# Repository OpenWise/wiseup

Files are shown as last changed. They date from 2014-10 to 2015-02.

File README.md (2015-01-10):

WiseUp
======

Wiseup is an intelligent home assistant open source framework that consists of three basic devices Gateway, Mediators and Sensors.

##Gateway
  Based on Raspberry Pi (Galileo/Edison in the future). All data is saved in this gateway that backs up the data on Cloud      service.
  All the important analytic scripts are running locally on the Gateway and analyzing sensor data every 3 seconds.
  
  Important modules
  - Wiseup service - this layer communicates with the sensors using Wiseup protocol.
  - Node.js services - this layer contains Web Service, connection to Mongo DB (local DB) and connection to Redis Service.
  - Redis service - Publish and Subscribe feature, also for fast data storage.
  - Mongo DB - local database.
  - Analytic services - based on node.js, executes analysis script on DB for detecting sensors features.
  - And more ...

##Mediator
  Main work frequency is 2.4Ghz with private protocol, but what if we want to use other sensors from EBay or other brands?
  For that we have the mediators that will convert from our protocol and frequency to other so we'll be able to consume
  other sensors.
  
##Sensors
  We have our own sensors running on batteries or directly from 5V power.
  
##Communication 
  nRF24l01 - 2.4Ghz very low cost and low power transceiver.
  
  RFComm - Private protocol for sensors/gateway communication. 

##Developers
- Yevgeniy Kiveisha - Linux and Embedded.
- Sharon Elihis - PCB Designer and JavaScript developer.
- Aviv Ron - Architect and senior software developer.
- Yuri Shapiro - SolidWorks designer and architect.
- Jennifer Kiveisha - UI Designer and web client developer.
- Roy Beiser - Architect

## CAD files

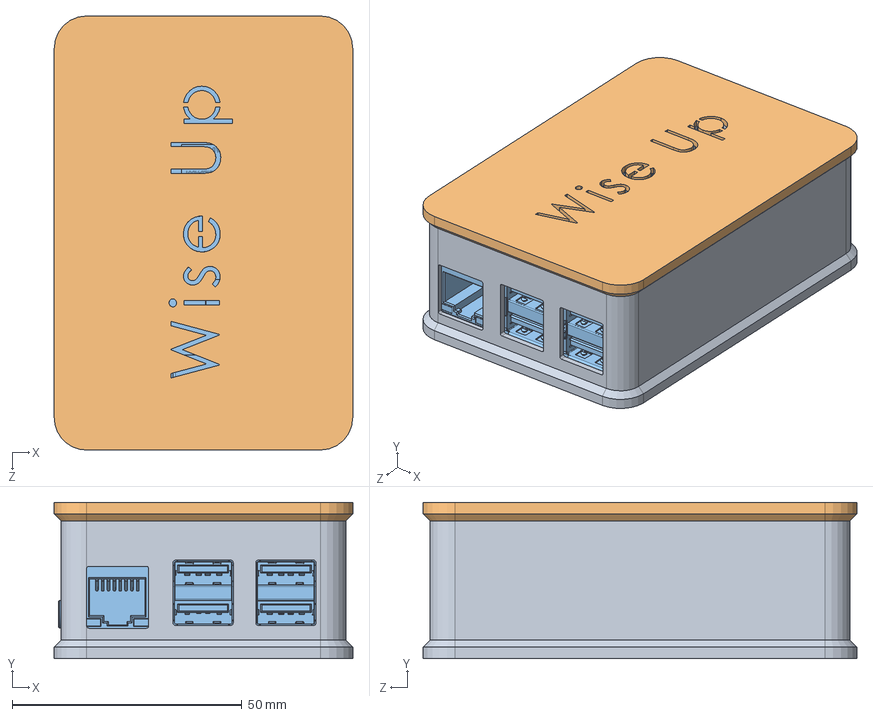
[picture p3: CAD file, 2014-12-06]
design/enclosure-design/Gateway Enclosure/Raspberrypi_B+/WiseUp - Assembly ver 2.SLDASM
65.0 x 34.0 x 94.5 mm
Case Rasp Bplus - Bottom
Case Rasp Bplus - Top
raspberrypi_b_+

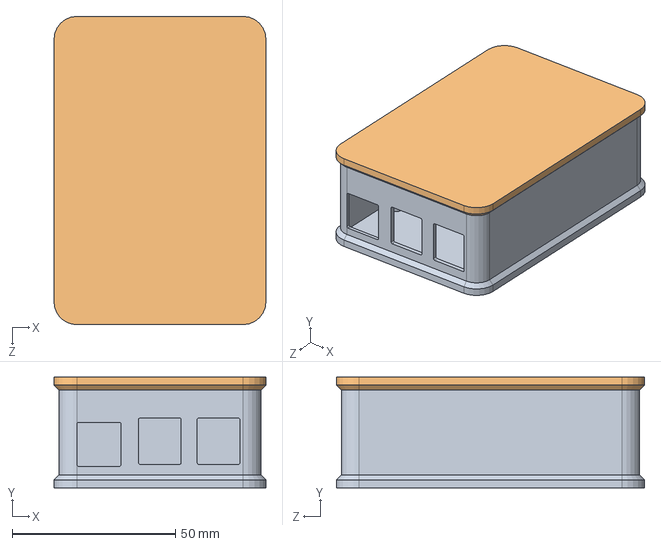
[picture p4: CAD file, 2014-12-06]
design/enclosure-design/Gateway Enclosure/Raspberrypi_B+/WiseUp - Case RBpi Bplus.SLDASM
65.0 x 34.0 x 94.5 mm
Case Rasp Bplus - Bottom
Case Rasp Bplus - Top

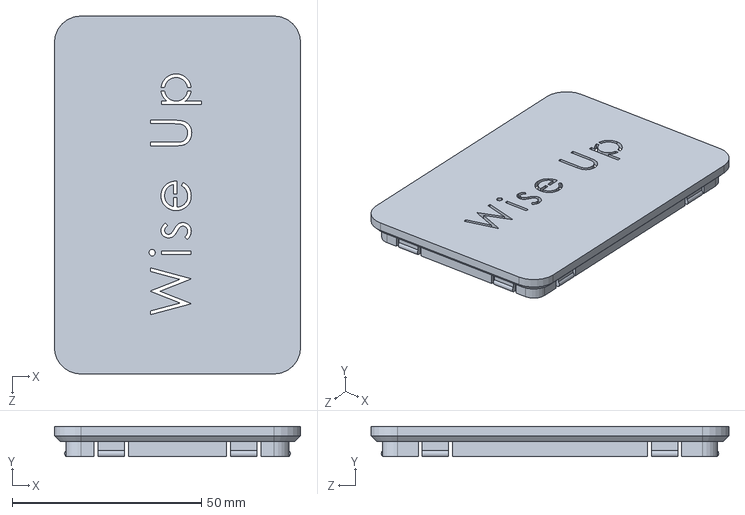
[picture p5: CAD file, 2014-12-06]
design/enclosure-design/Gateway Enclosure/Raspberrypi_B+/Case Rasp Bplus - Top.SLDPRT
65.0 x 8.00 x 94.5 mm

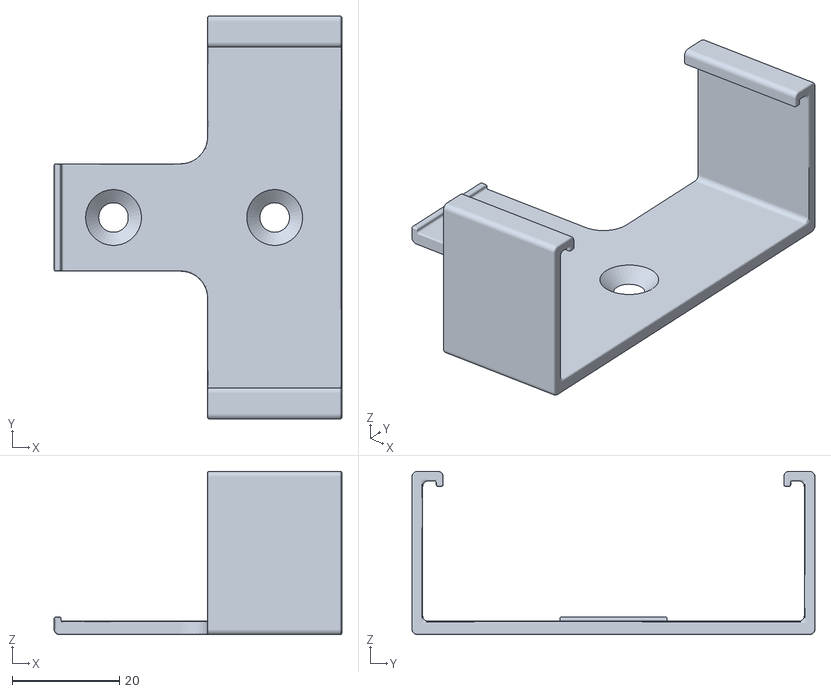
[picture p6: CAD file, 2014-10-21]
design/enclosure-design/microcontroller-gateway/Support 1.1.STL
53.6 x 75.0 x 30.4

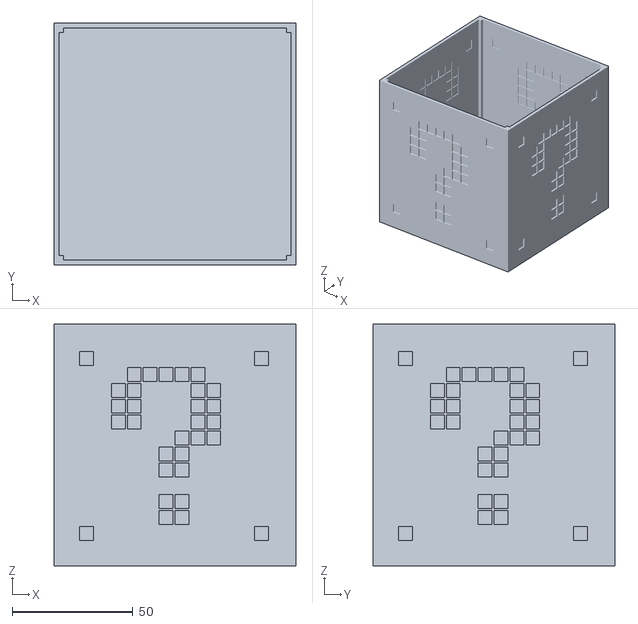
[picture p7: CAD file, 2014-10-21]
design/enclosure-design/qbox.stl
100.0 x 100.0 x 100.0

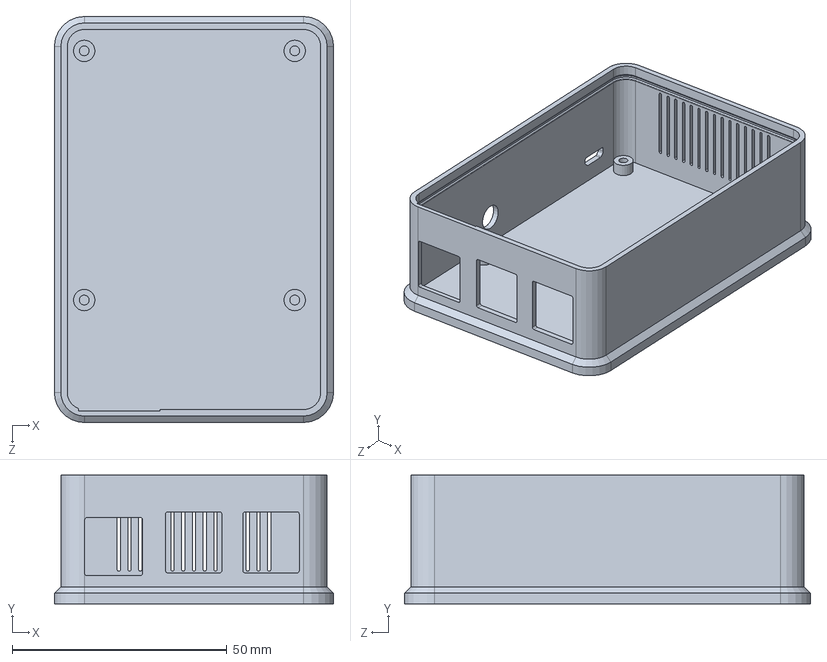
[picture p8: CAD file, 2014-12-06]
design/enclosure-design/Gateway Enclosure/Raspberrypi_B+/Case Rasp Bplus - Bottom.SLDPRT
65.0 x 30.0 x 94.5 mm

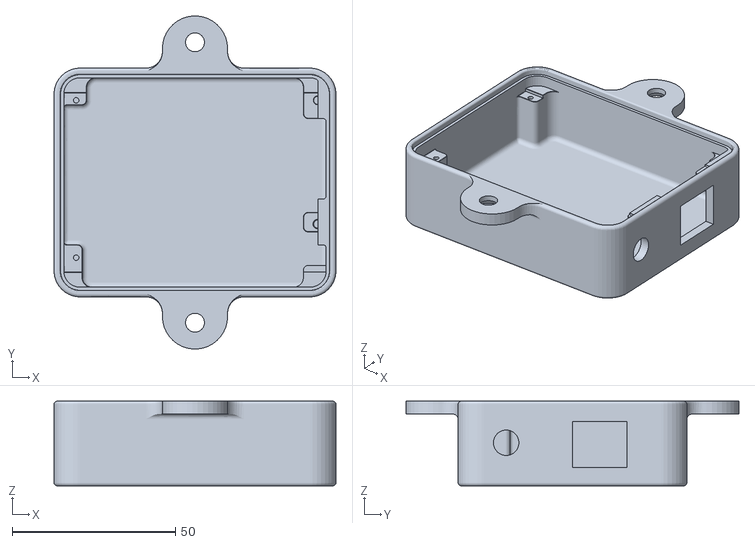
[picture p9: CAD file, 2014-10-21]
design/enclosure-design/microcontroller-gateway/BOX_UP Support 1.1.STL
86.5 x 102.1 x 26.0

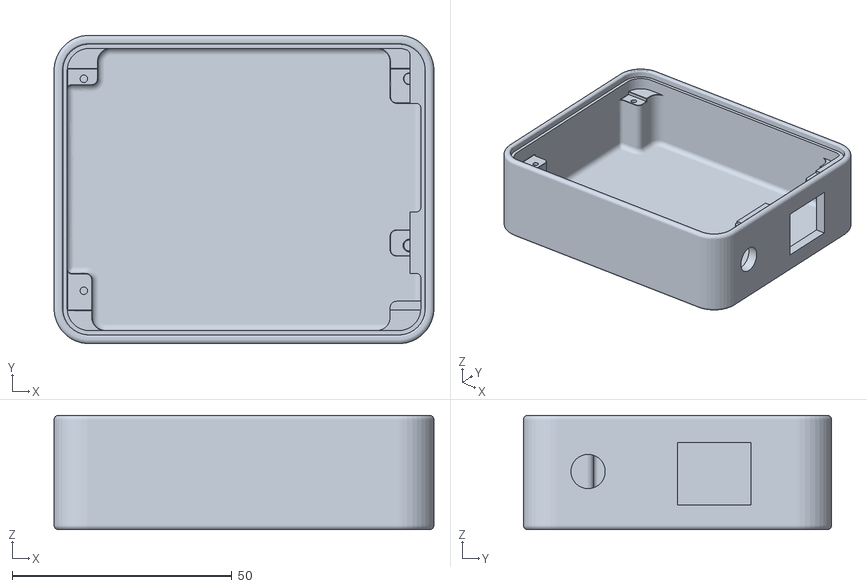
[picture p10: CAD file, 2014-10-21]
design/enclosure-design/microcontroller-gateway/BOX_UP 1.1.STL
86.5 x 70.2 x 26.0

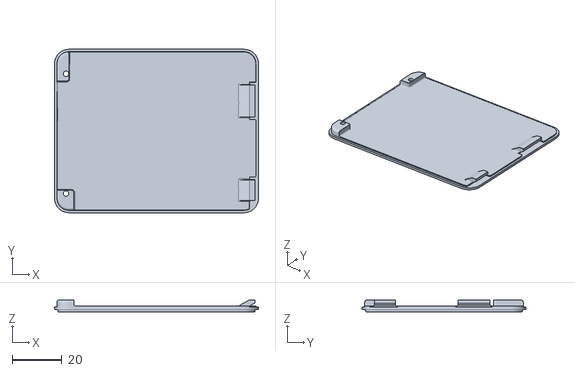
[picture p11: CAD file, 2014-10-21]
design/enclosure-design/microcontroller-gateway/Cover 3.1.STL
82.2 x 65.9 x 5.00

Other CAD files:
design/enclosure-design/Gateway Enclosure/Raspberrypi_B+/Case Rasp Bplus - Bottom.STL
design/enclosure-design/Gateway Enclosure/Raspberrypi_B+/Case Rasp Bplus - Top.STL

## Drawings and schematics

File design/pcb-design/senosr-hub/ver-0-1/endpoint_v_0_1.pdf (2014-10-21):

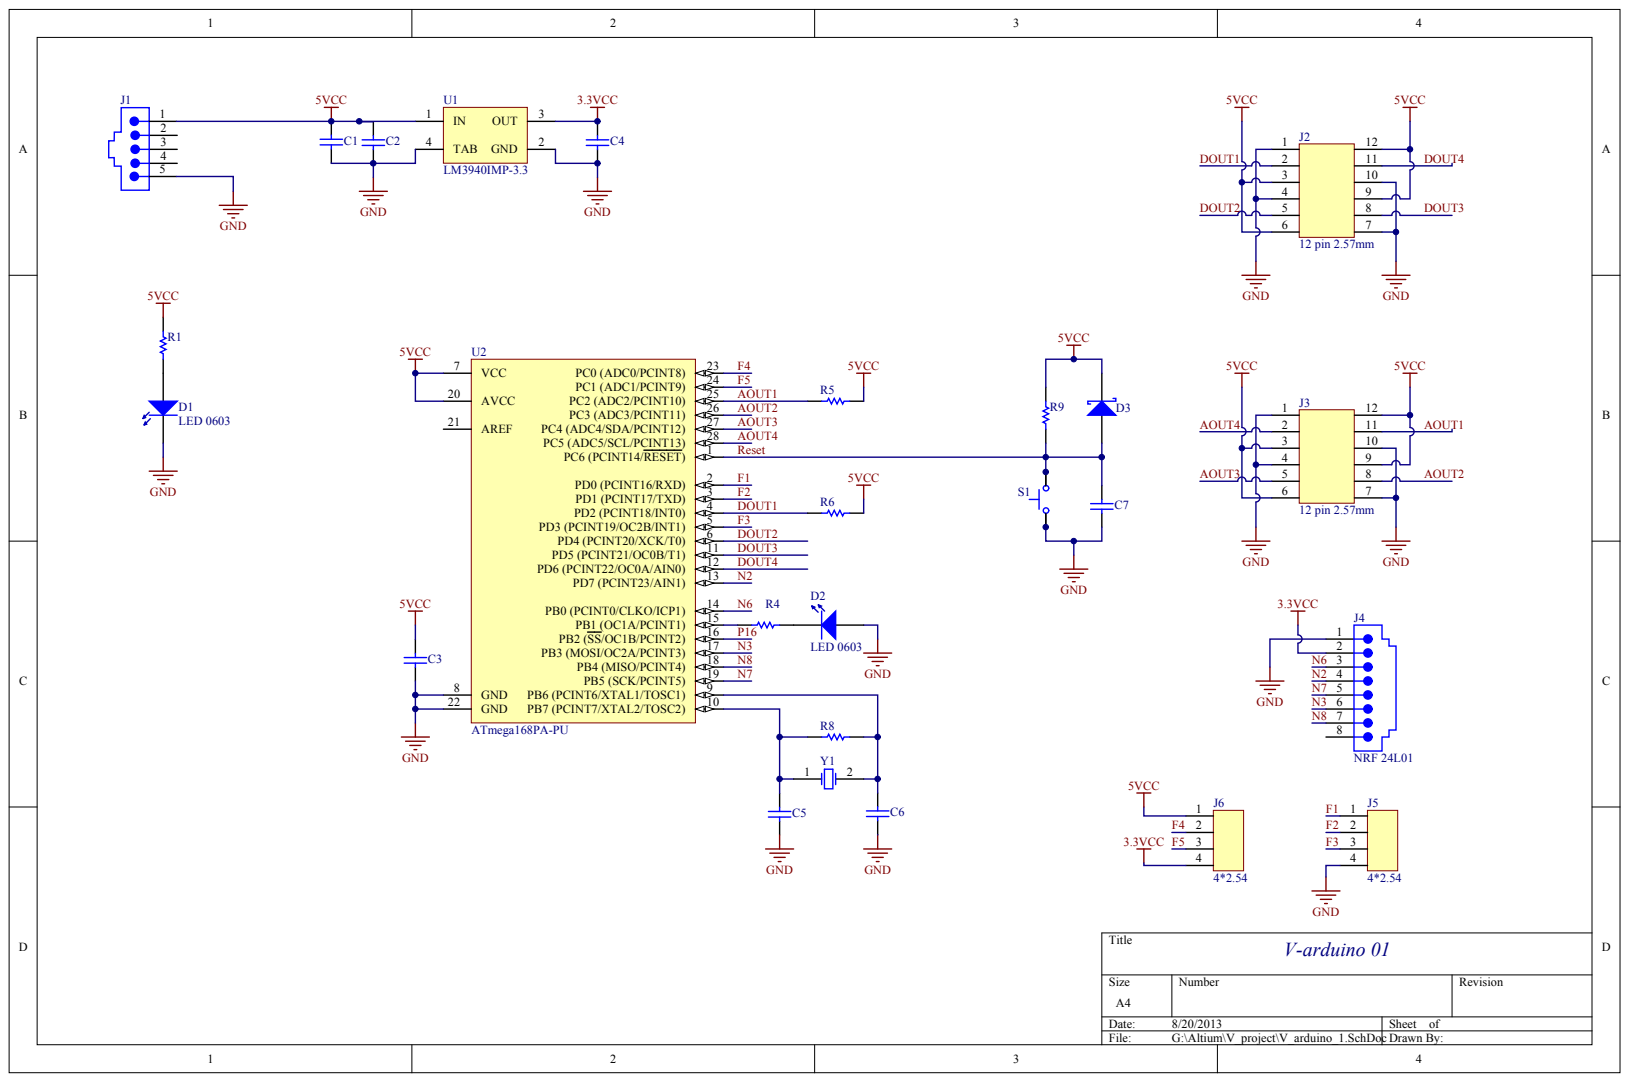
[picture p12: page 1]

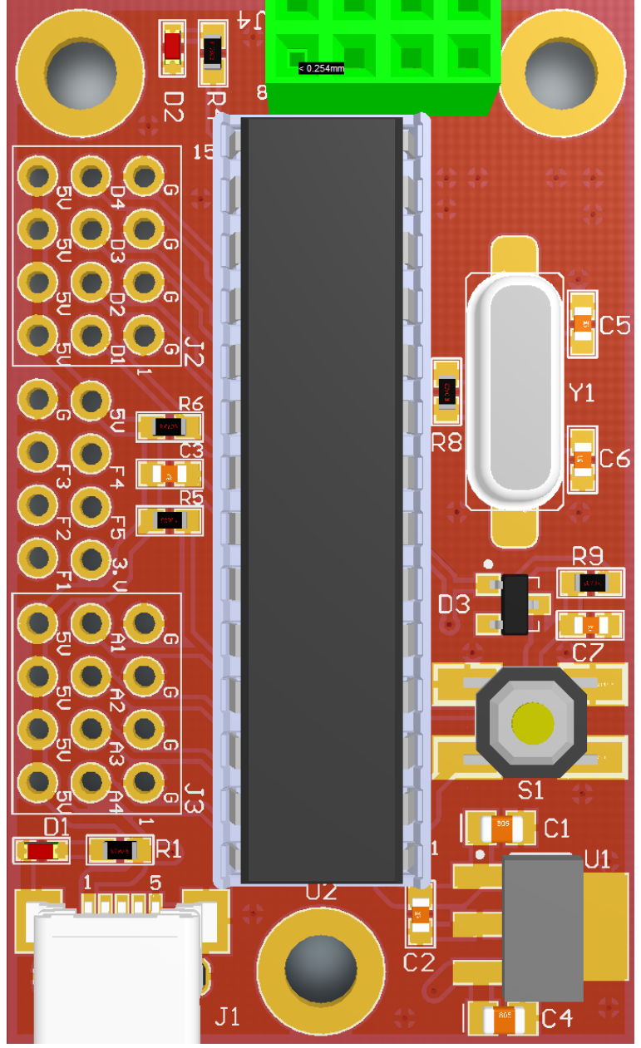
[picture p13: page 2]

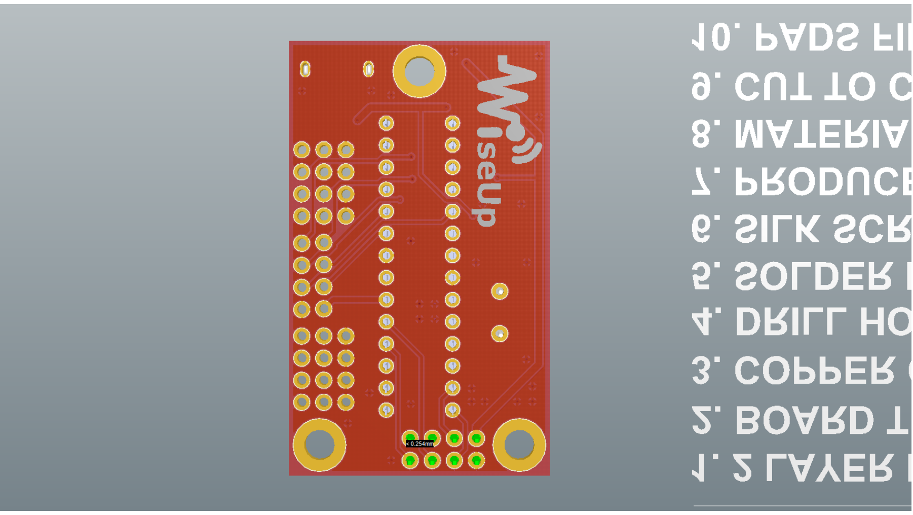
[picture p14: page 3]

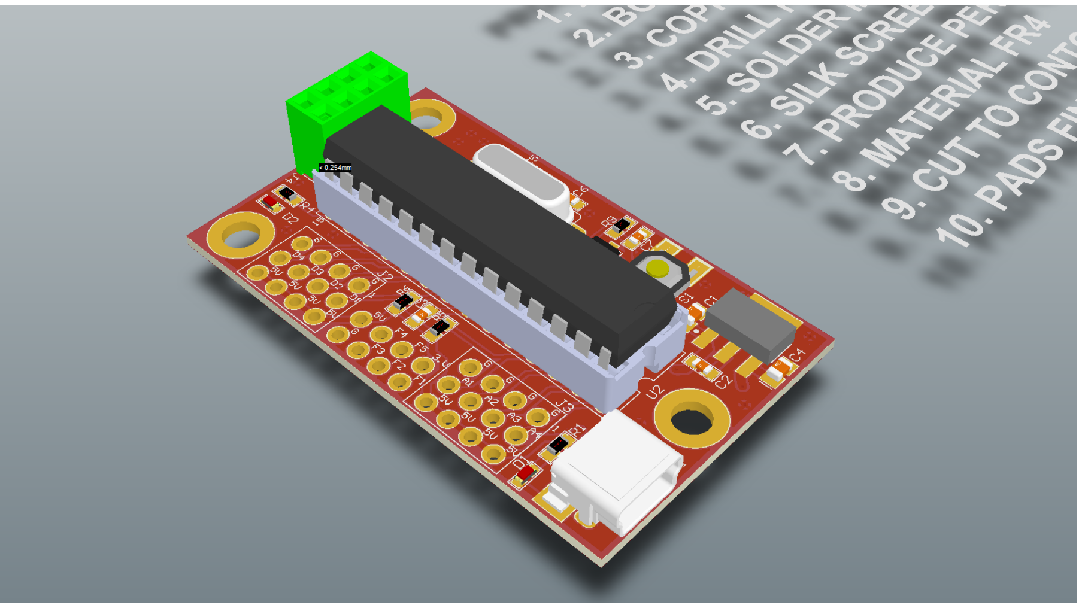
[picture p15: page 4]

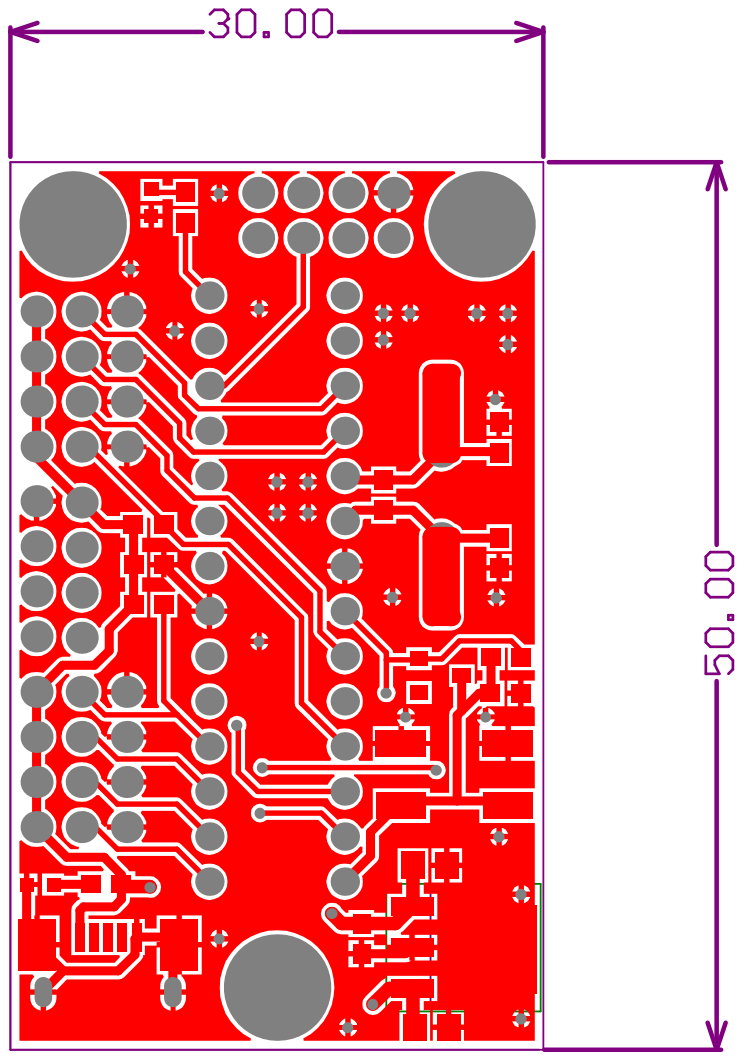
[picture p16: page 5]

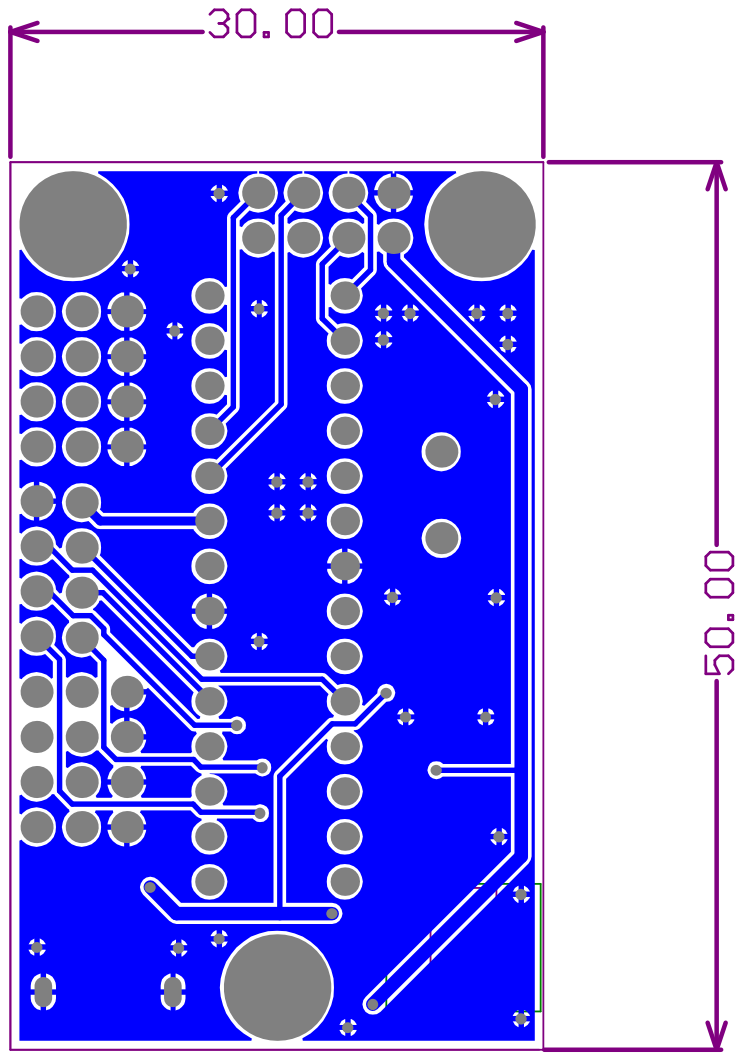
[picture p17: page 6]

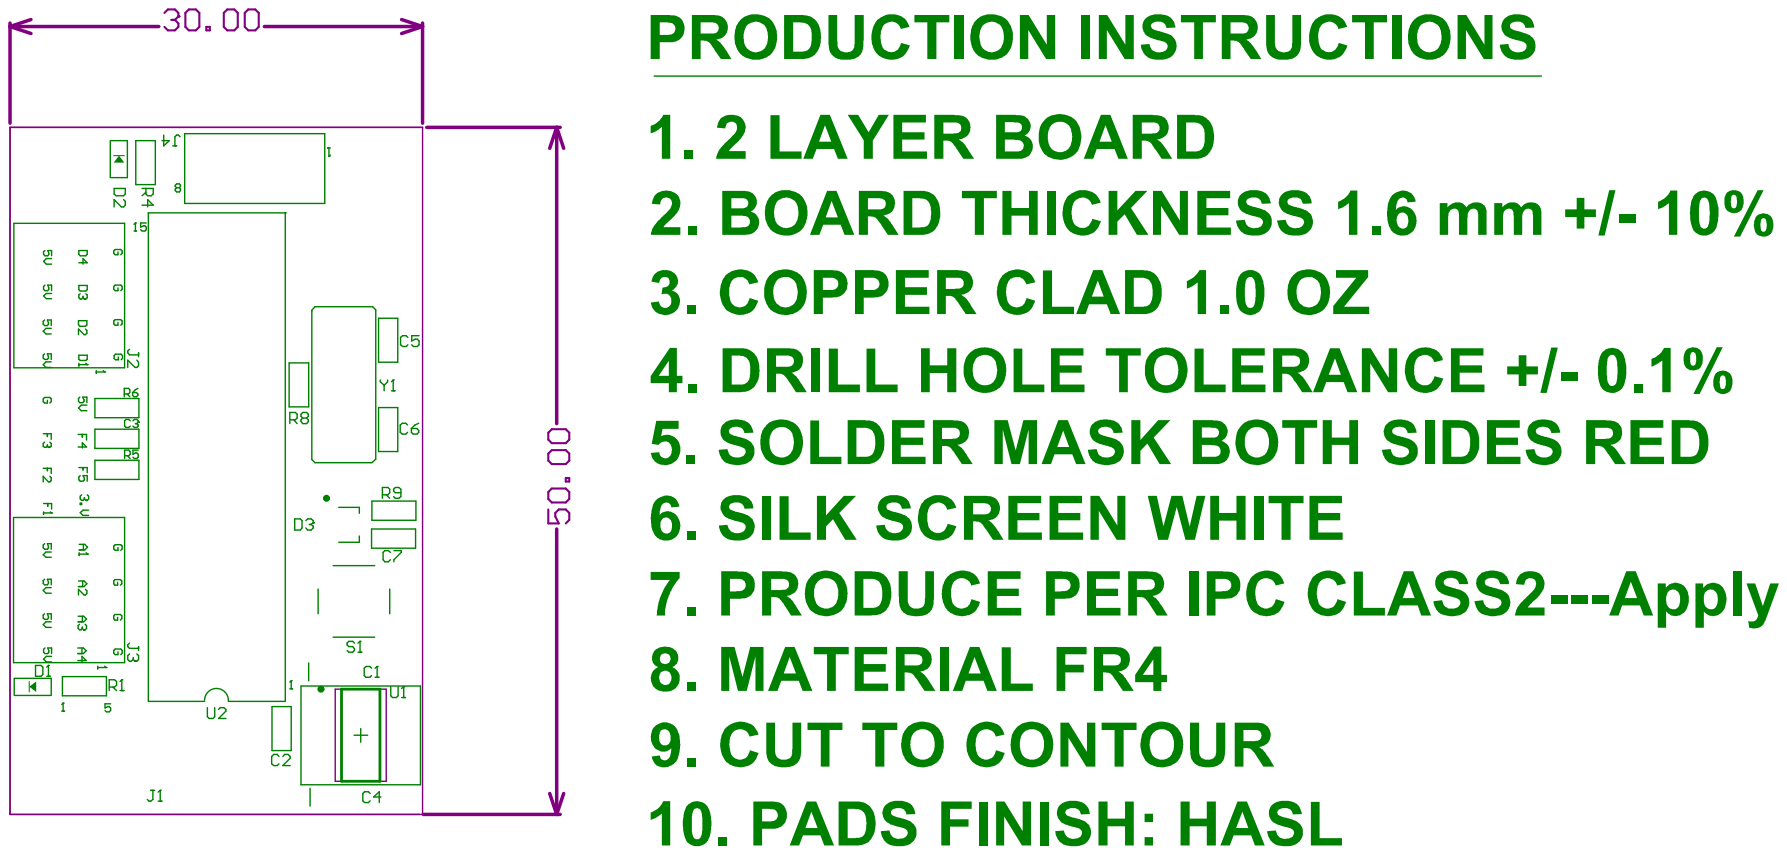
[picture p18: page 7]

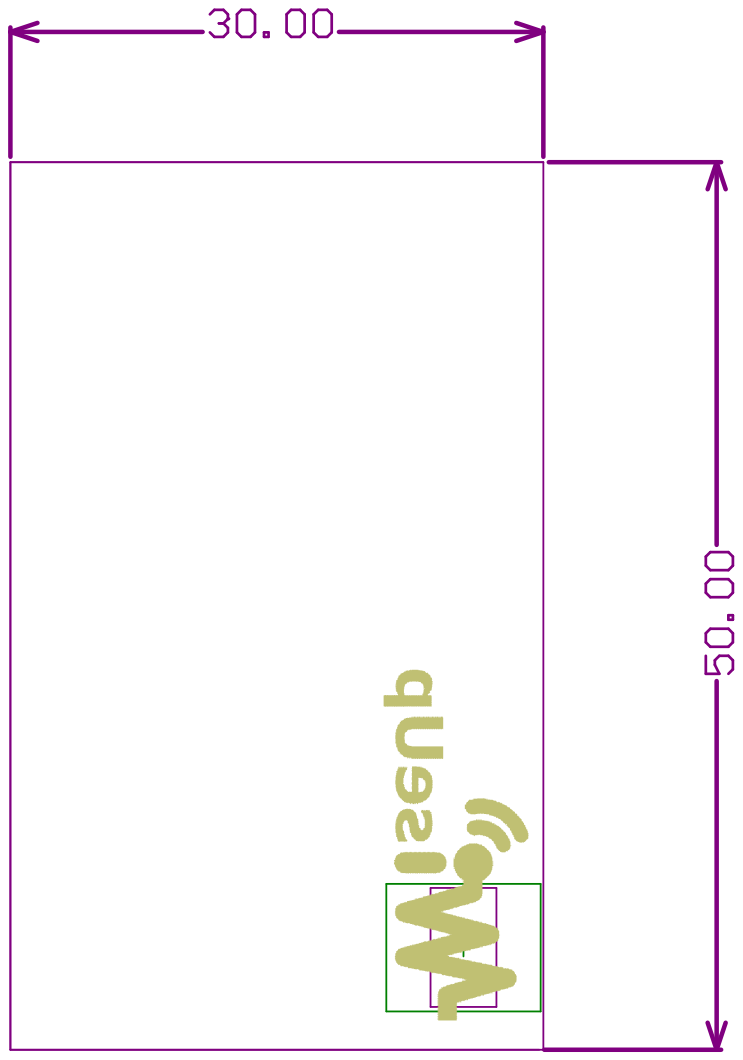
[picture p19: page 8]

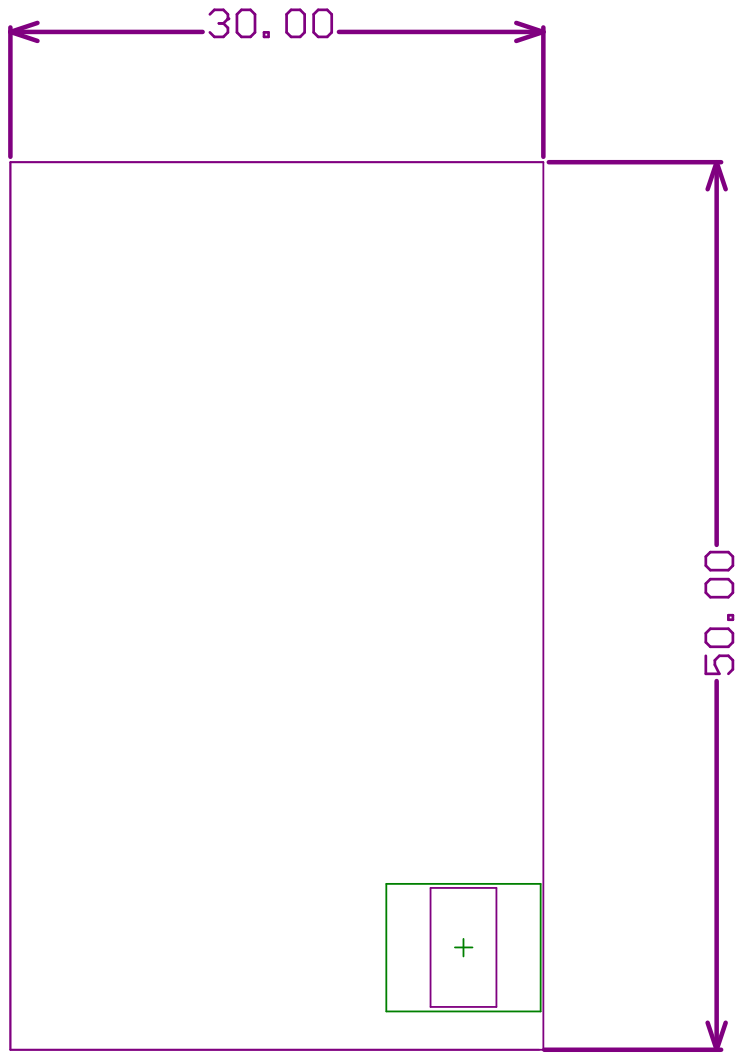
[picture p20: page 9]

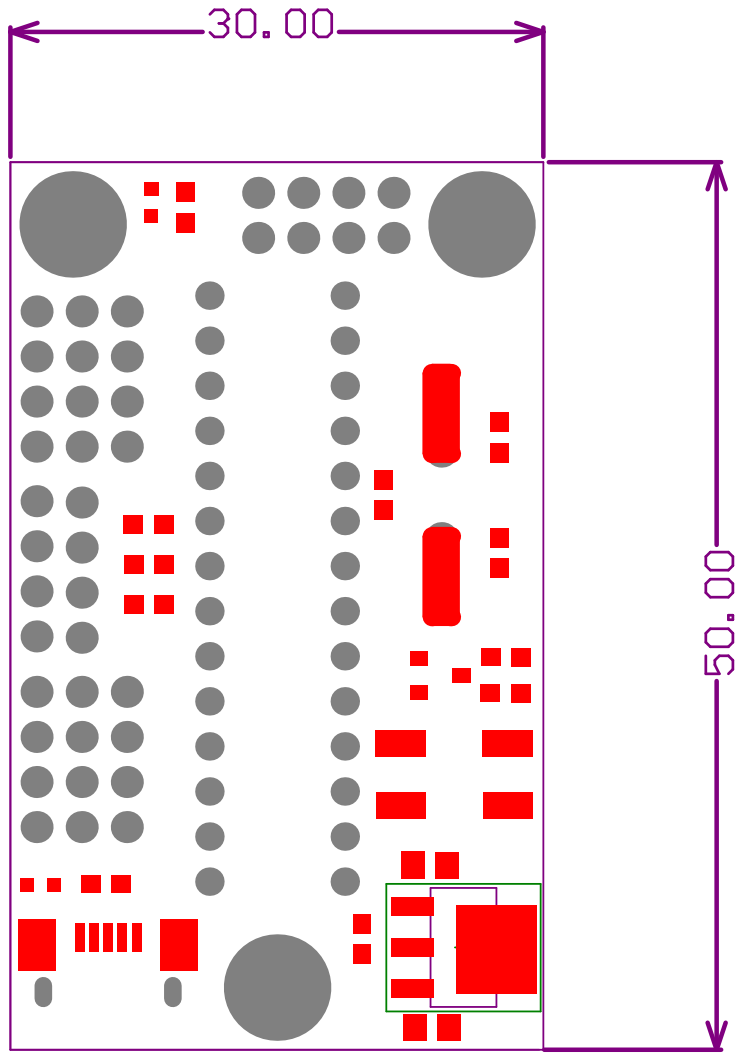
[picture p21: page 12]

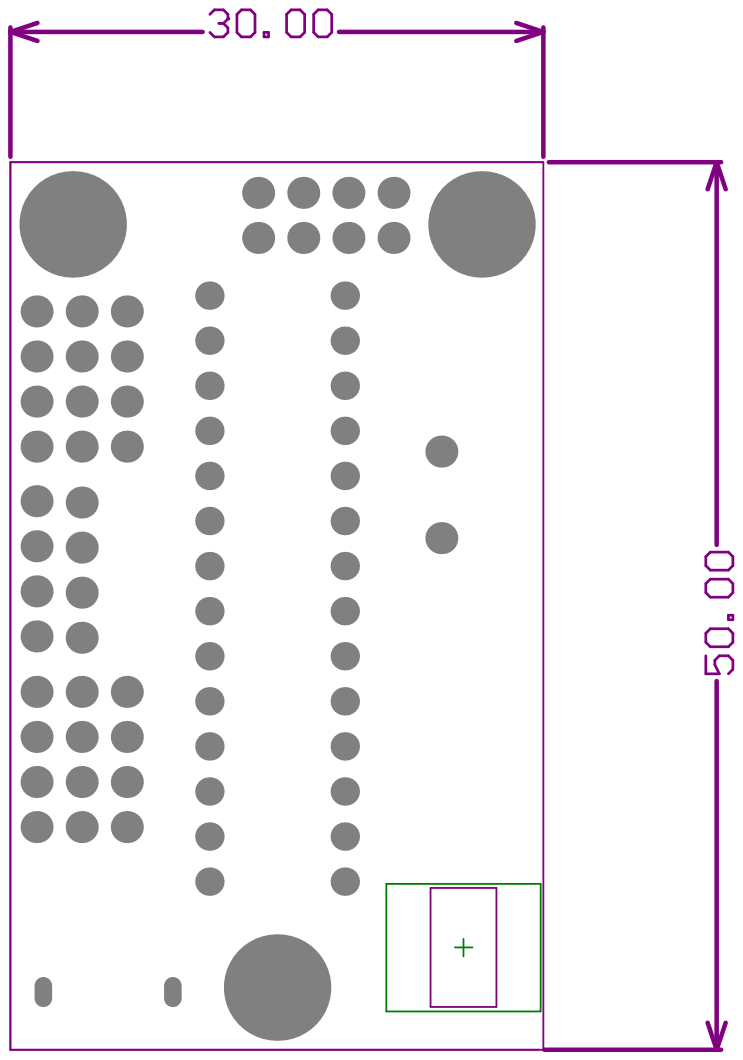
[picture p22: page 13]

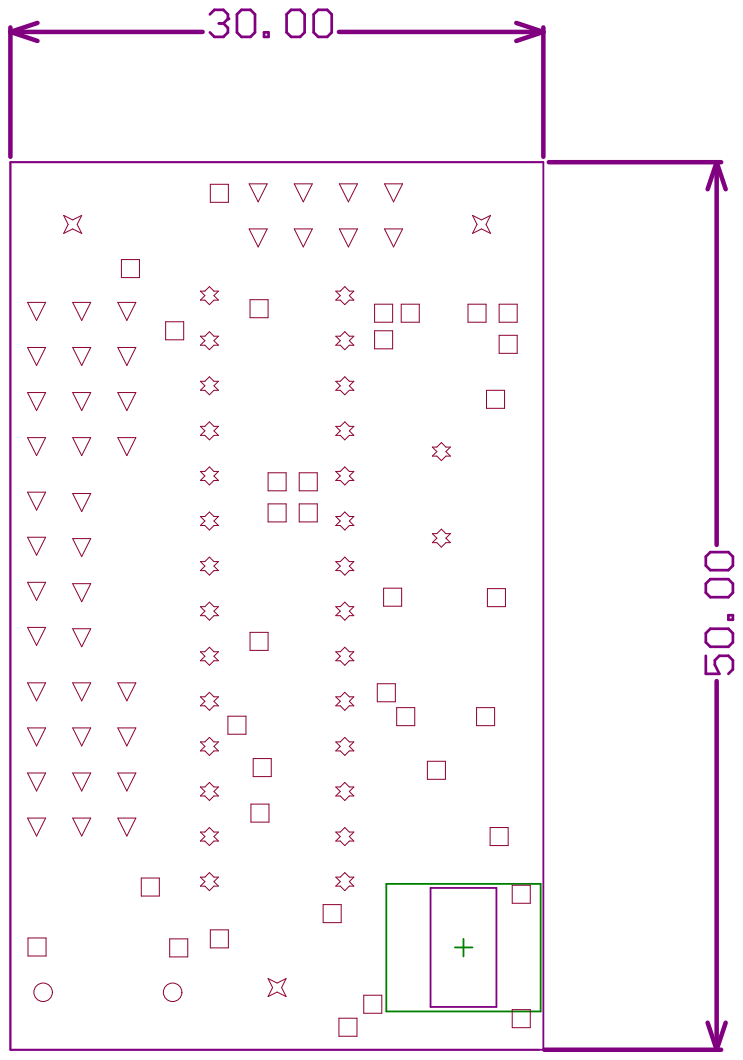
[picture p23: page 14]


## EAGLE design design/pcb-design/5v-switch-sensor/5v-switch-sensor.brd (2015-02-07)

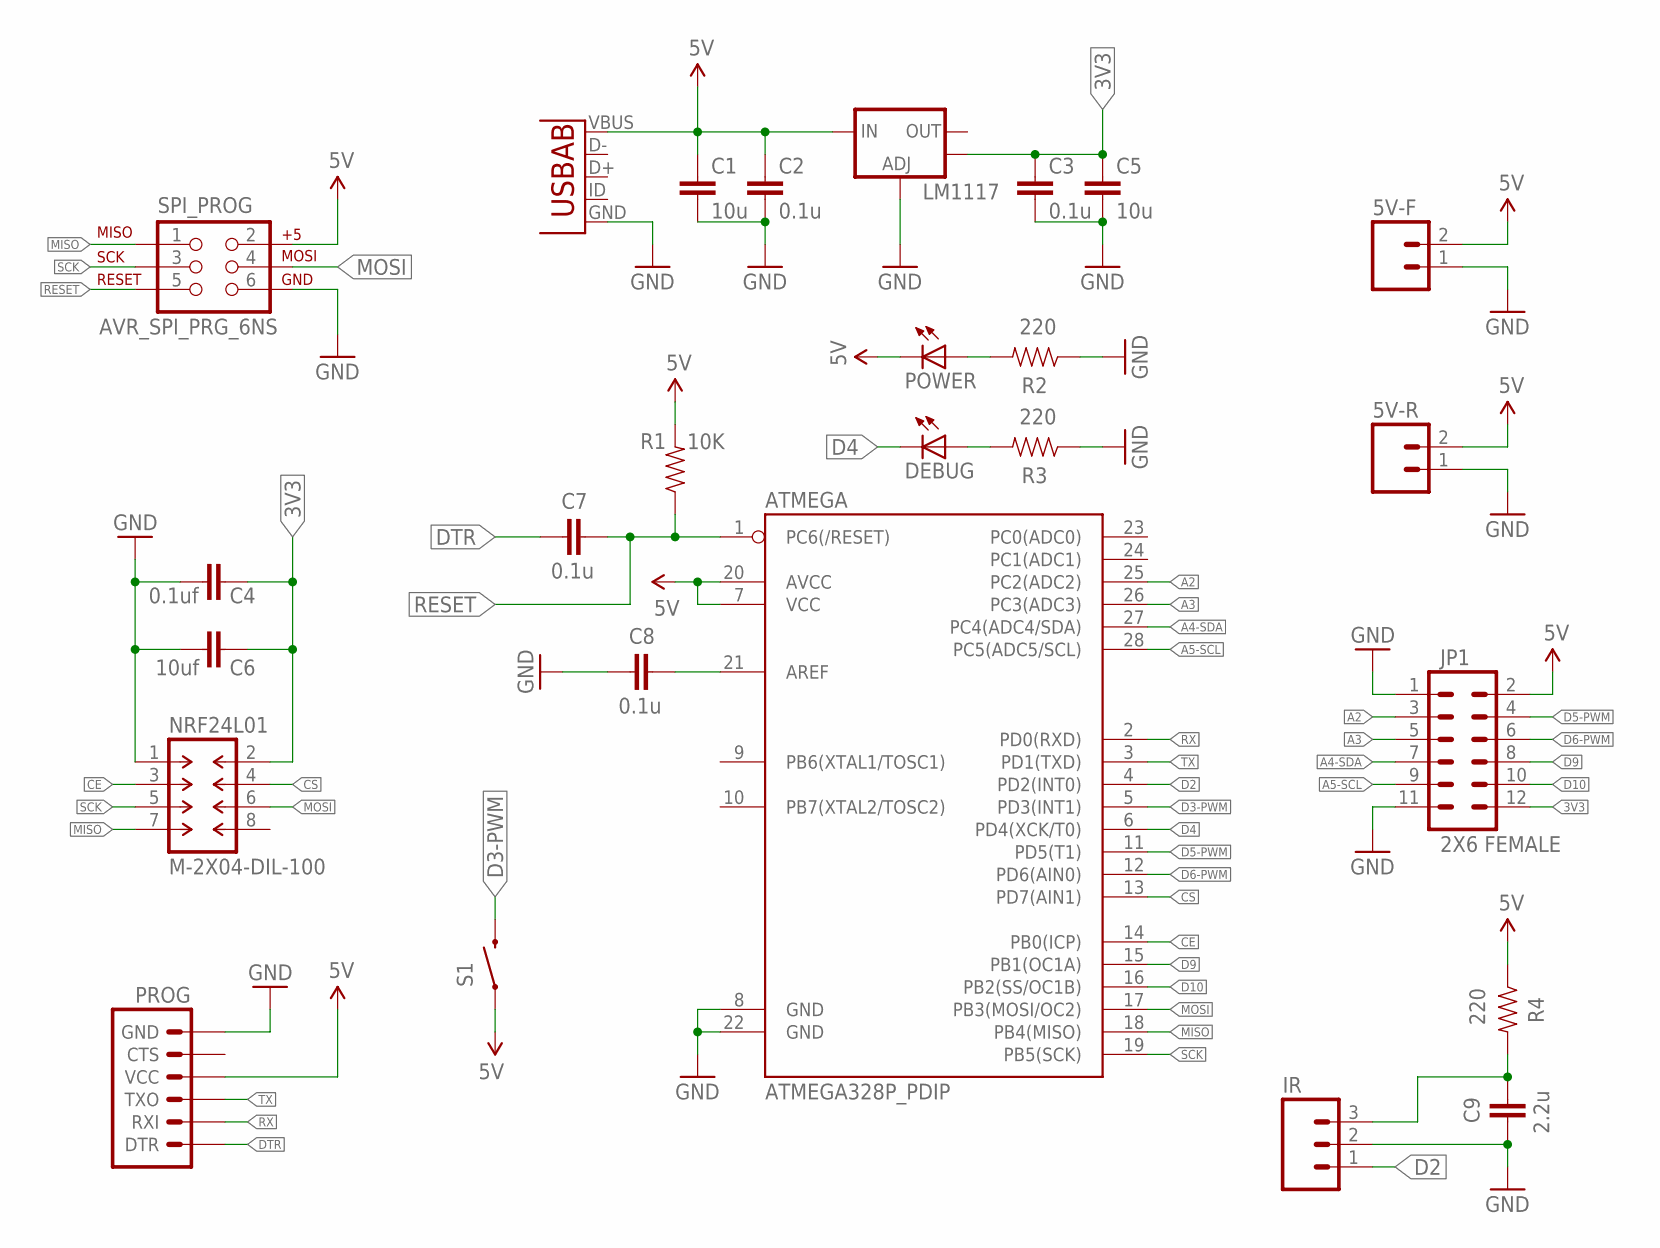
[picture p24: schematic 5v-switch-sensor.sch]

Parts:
5V-F, 5V-R: M02PTH; 1X02
ATMEGA: ATMEGA328P_PDIP; DIL28-3
C1, C5: 10u; 0805
C2, C3, C7, C8: 0.1u; 0805
C4: 0.1uf; 0805
C6: 10uf; 0805
C9: 2.2u; 0805
DEBUG: LEDCHIPLED_0805; CHIPLED_0805
IR: M03PTH; 1X03
JP1: 2X6 FEMALE; 2X6
LM1117: V_REG_LM1117SOT223; SOT223
NRF24L01: M-2X04-DIL-100; DIL-100-2X04
POWER: LEDCHIPLED_0805; CHIPLED_0805
PROG: ARDUINO_SERIAL_PROGRAMPTH; 1X06
R1: 10K; 0805
R2, R3, R4: 220; 0805
S1: SWITCH-MOMENTARY-2SMD-1101NE; TACTILE-SWITCH-1101NE
SPI_PROG: AVR_SPI_PRG_6NS; 2X3-NS
U1: USB-AB; USB-AB-MICRO-SMD

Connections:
3V3: C3.1, C4.1, C5.1, C6.1, JP1.12, LM1117.4 (OUT), NRF24L01.2
5V: 5V-F.2, 5V-R.2, ATMEGA.7 (VCC), ATMEGA.20 (AVCC), C1.1, C2.1, JP1.2, LM1117.3 (IN), POWER.C, PROG.4 (VCC), R1.2, R4.1, S1.1, SPI_PROG.2, U1.VBUS
A2: ATMEGA.25 (PC2(ADC2)), JP1.3
A3: ATMEGA.26 (PC3(ADC3)), JP1.5
A4-SDA: ATMEGA.27 (PC4(ADC4/SDA)), JP1.7
A5-SCL: ATMEGA.28 (PC5(ADC5/SCL)), JP1.9
CE: ATMEGA.14 (PB0(ICP)), NRF24L01.3
CS: ATMEGA.13 (PD7(AIN1)), NRF24L01.4
D2: ATMEGA.4 (PD2(INT0)), IR.1
D3-PWM: ATMEGA.5 (PD3(INT1)), S1.2
D4: ATMEGA.6 (PD4(XCK/T0)), DEBUG.C
D5-PWM: ATMEGA.11 (PD5(T1)), JP1.4
D6-PWM: ATMEGA.12 (PD6(AIN0)), JP1.6
D9: ATMEGA.15 (PB1(OC1A)), JP1.8
D10: ATMEGA.16 (PB2(SS/OC1B)), JP1.10
DTR: C7.1, PROG.1 (DTR)
GND: 5V-F.1, 5V-R.1, ATMEGA.8 (GND), ATMEGA.22 (GND), C1.2, C2.2, C3.2, C4.2, C5.2, C6.2, C8.1, C9.1, IR.2, JP1.1, JP1.11, LM1117.1 (ADJ), NRF24L01.1, PROG.6 (GND), R2.1, R3.1, SPI_PROG.6, U1.GND
MISO: ATMEGA.18 (PB4(MISO)), NRF24L01.7, SPI_PROG.1
MOSI: ATMEGA.17 (PB3(MOSI/OC2)), NRF24L01.6, SPI_PROG.4
unnamed: C9.2, IR.3, R4.2
unnamed: POWER.A, R2.2
unnamed: ATMEGA.21 (AREF), C8.2
unnamed: DEBUG.A, R3.2
RESET: ATMEGA.1 (PC6(/RESET)), C7.2, R1.1, SPI_PROG.5
RX: ATMEGA.2 (PD0(RXD)), PROG.2 (RXI)
SCK: ATMEGA.19 (PB5(SCK)), NRF24L01.5, SPI_PROG.3
TX: ATMEGA.3 (PD1(TXD)), PROG.3 (TXO)

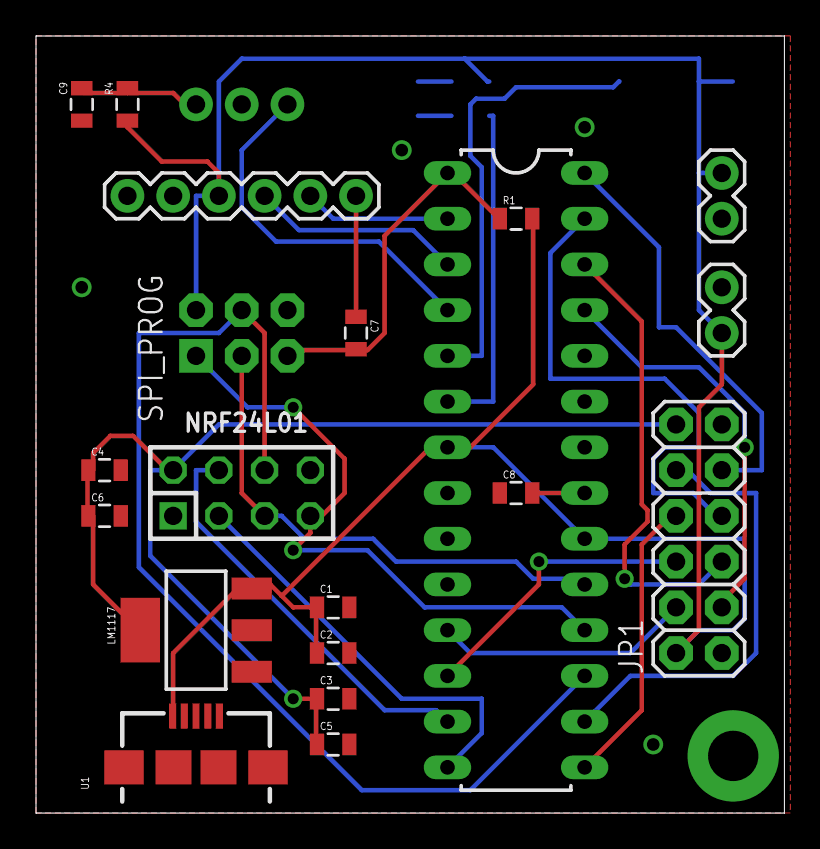
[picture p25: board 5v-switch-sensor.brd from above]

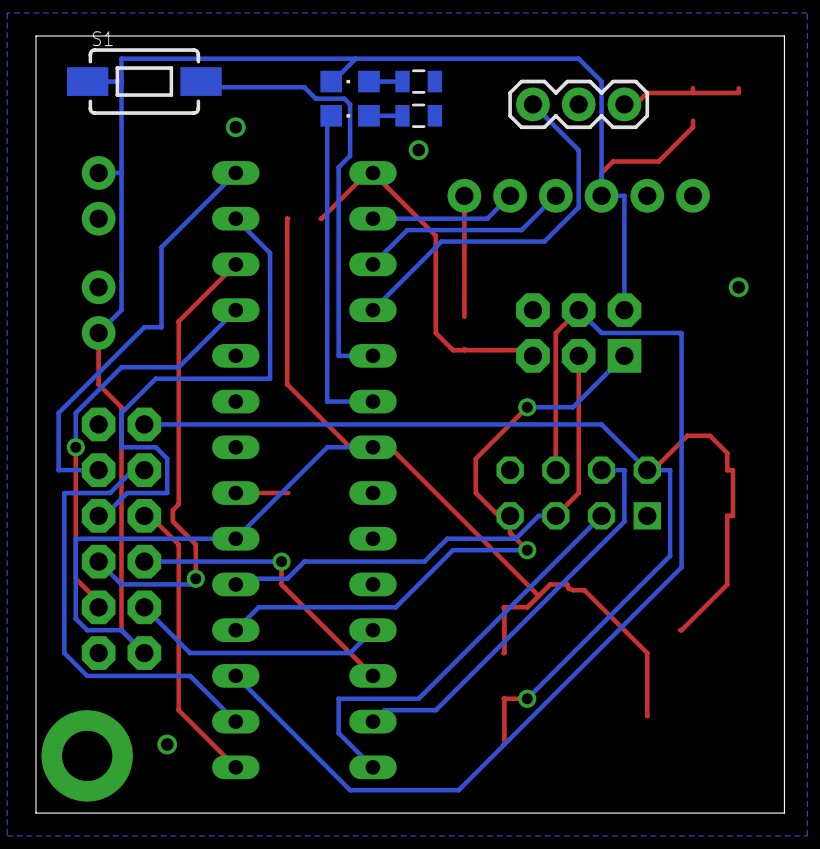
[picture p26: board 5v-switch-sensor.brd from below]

Board: 2 copper layers, 41.6 x 43.2 mm, 26 parts (6 on the bottom side), 27 nets.

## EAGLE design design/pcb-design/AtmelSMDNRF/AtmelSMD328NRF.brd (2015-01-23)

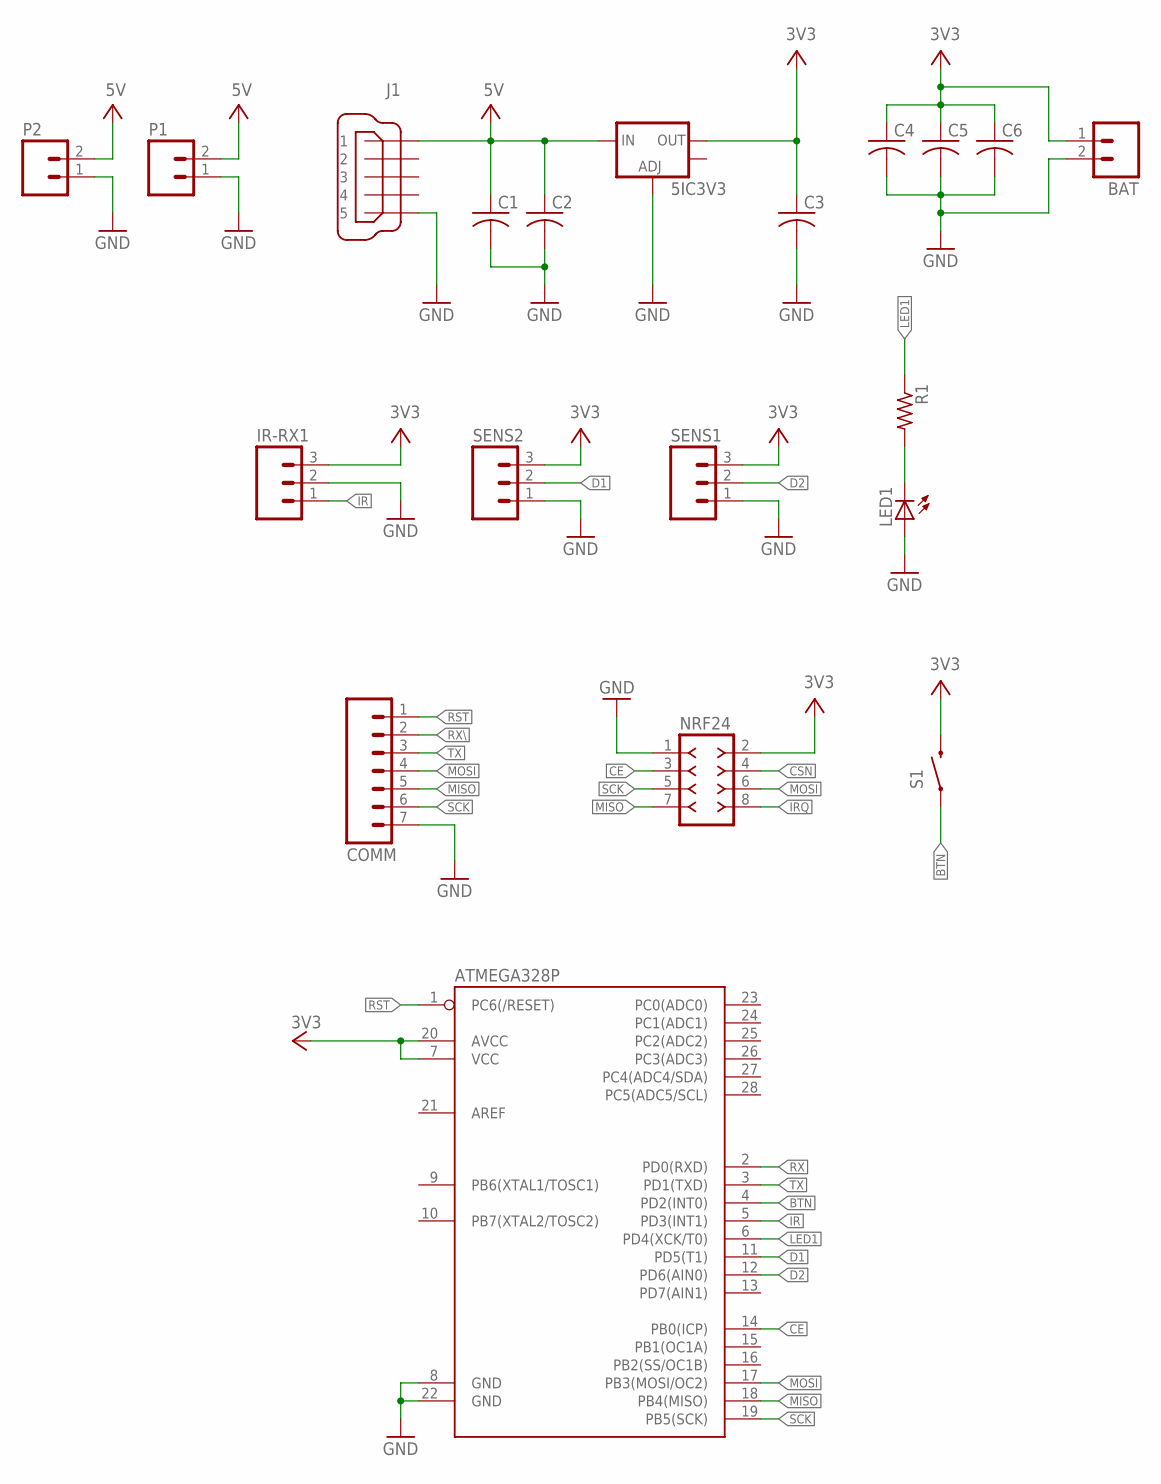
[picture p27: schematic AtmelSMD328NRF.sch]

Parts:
5IC3V3: V_REG_LM1117SOT223; SOT223
ATMEGA328P: ATMEGA328P_PDIP; DIL28-3
BAT: M02PTH; 1X02
C1, C2, C3, C4, C5, C6: C-USC0805; C0805
COMM: M07; 1X07
IR-RX1: M03PTH; 1X03
J1: MICRO-USB-ZX62R-B-5P; ZX62R-B-5P
LED1: LEDCHIPLED_0805; CHIPLED_0805
NRF24: F-2X04-DIL-100; DIL-100-2X04
P1, P2: M02PTH; 1X02
R1: R-US_R0805; R0805
S1: SWITCH-MOMENTARY-2SMD-1101NE; TACTILE-SWITCH-1101NE
SENS1, SENS2: M03PTH; 1X03

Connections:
+3V3: 5IC3V3.2 (OUT), ATMEGA328P.7 (VCC), ATMEGA328P.20 (AVCC), BAT.1, C3.1, C4.1, C5.1, C6.1, IR-RX1.3, NRF24.2, S1.2, SENS1.3, SENS2.3
+5V: 5IC3V3.3 (IN), C1.1, C2.1, J1.1, P1.2, P2.2
BTN: ATMEGA328P.4 (PD2(INT0)), S1.1
CE: ATMEGA328P.14 (PB0(ICP)), NRF24.3
CSN: NRF24.4
D1: ATMEGA328P.11 (PD5(T1)), SENS2.2
D2: ATMEGA328P.12 (PD6(AIN0)), SENS1.2
GND: 5IC3V3.1 (ADJ), ATMEGA328P.8 (GND), ATMEGA328P.22 (GND), BAT.2, C1.2, C2.2, C3.2, C4.2, C5.2, C6.2, COMM.7, IR-RX1.2, J1.5, LED1.A, NRF24.1, P1.1, P2.1, SENS1.1, SENS2.1
IR: ATMEGA328P.5 (PD3(INT1)), IR-RX1.1
IRQ: NRF24.8
LED1: ATMEGA328P.6 (PD4(XCK/T0)), R1.1
MISO: ATMEGA328P.18 (PB4(MISO)), COMM.5, NRF24.7
MOSI: ATMEGA328P.17 (PB3(MOSI/OC2)), COMM.4, NRF24.6
unnamed: LED1.C, R1.2
RST: ATMEGA328P.1 (PC6(/RESET)), COMM.1
RX: ATMEGA328P.2 (PD0(RXD))
RX\: COMM.2
SCK: ATMEGA328P.19 (PB5(SCK)), COMM.6, NRF24.5
TX: ATMEGA328P.3 (PD1(TXD)), COMM.3

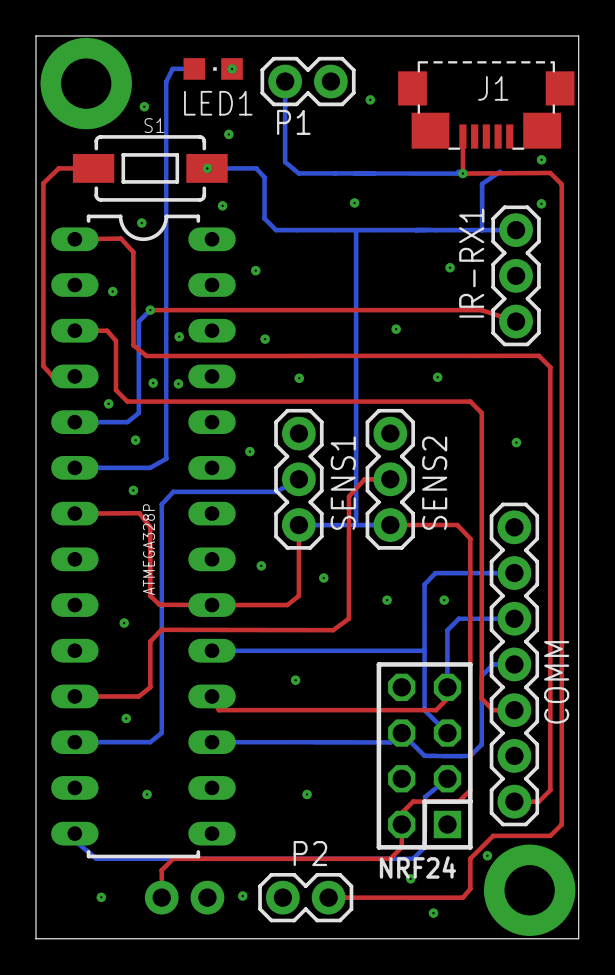
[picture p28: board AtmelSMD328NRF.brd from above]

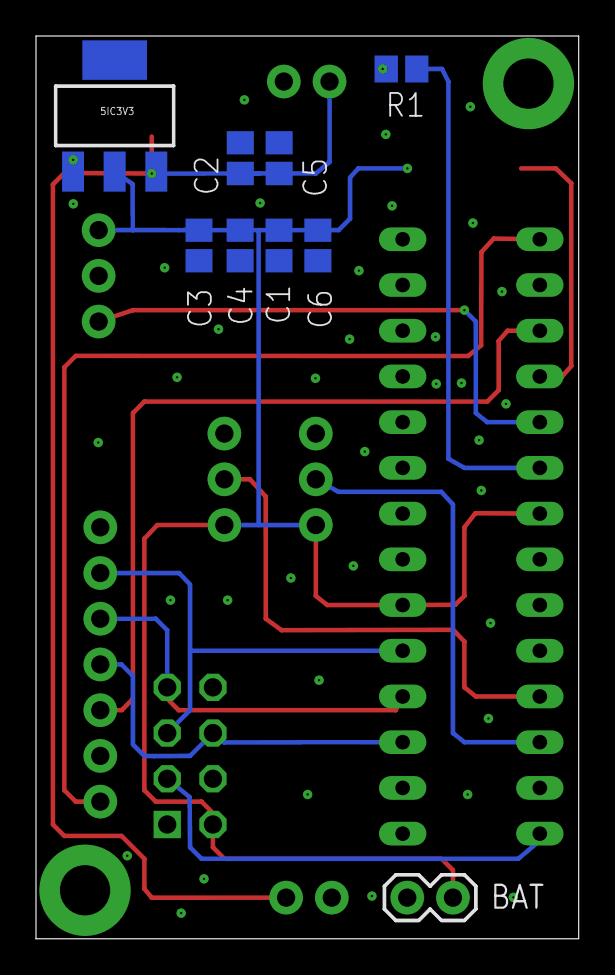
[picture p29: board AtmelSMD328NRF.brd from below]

Board: 2 copper layers, 30.1 x 50.2 mm, 20 parts (9 on the bottom side), 15 nets.

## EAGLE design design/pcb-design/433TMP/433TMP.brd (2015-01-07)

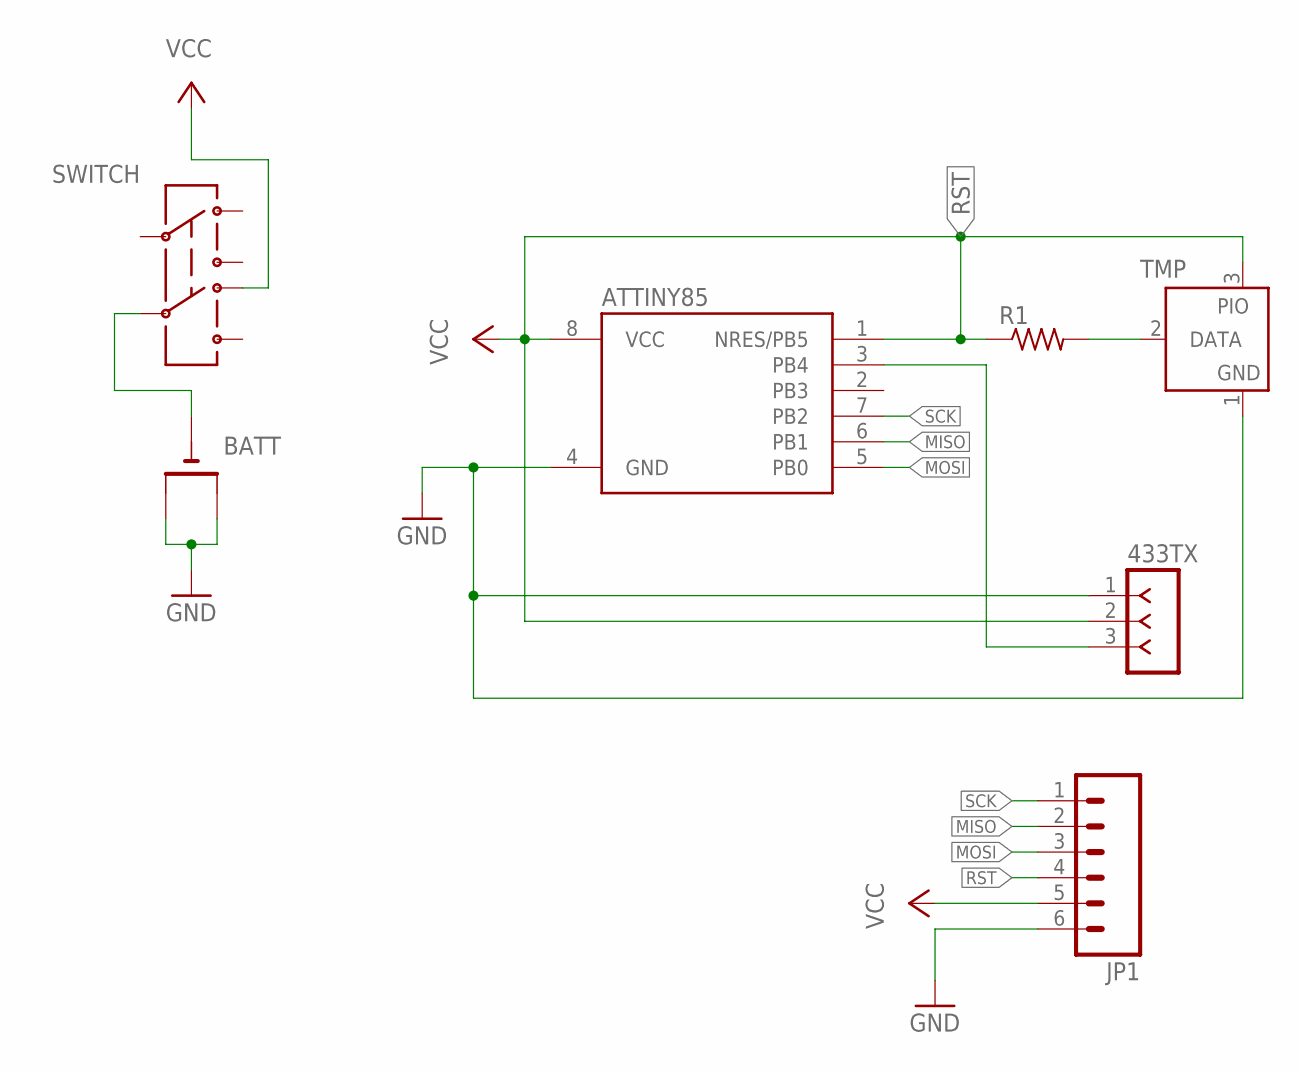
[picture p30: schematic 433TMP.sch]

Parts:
433TX: F-1X03-SIP-100-40; SIP-100-03-40
ATTINY85: ATTINY85-S; SOIC8_EIAJ_208MIL
BATT: CR2032SMT; CR2032-SMD
JP1: M06SILK_FEMALE_PTH; 1X06
R1: R-US_R0805; R0805
SWITCH: AYZ0202
TMP: DS2405; TO92-

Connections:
GND: 433TX.1, ATTINY85.4 (GND), BATT.+$1 (+), BATT.+$2 (+1), JP1.6, TMP.1 (GND)
MISO: ATTINY85.6 (PB1), JP1.2
MOSI: ATTINY85.5 (PB0), JP1.3
unnamed: 433TX.3, ATTINY85.3 (PB4)
unnamed: R1.2, TMP.2 (DATA)
unnamed: BATT.-, SWITCH.5
RST: 433TX.2, ATTINY85.1 (NRES/PB5), ATTINY85.8 (VCC), JP1.4, JP1.5, R1.1, SWITCH.6 (4), TMP.3 (PIO)
SCK: ATTINY85.7 (PB2), JP1.1

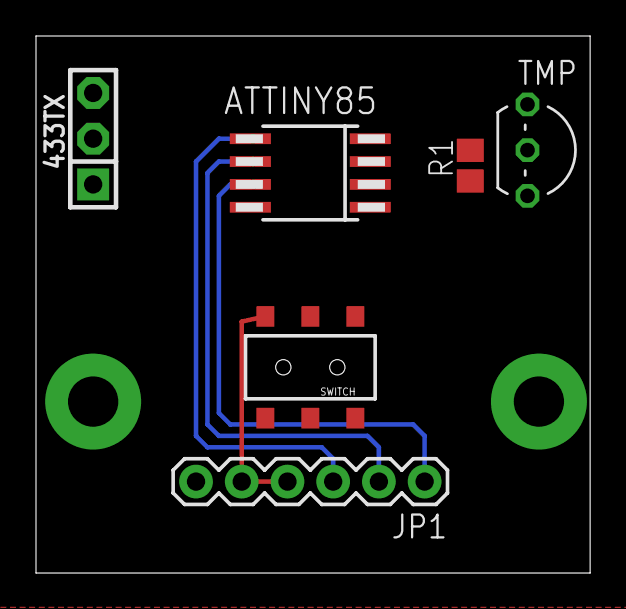
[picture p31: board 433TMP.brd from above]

Board: 2 copper layers, 30.8 x 29.8 mm, 7 parts (1 on the bottom side), 8 nets.

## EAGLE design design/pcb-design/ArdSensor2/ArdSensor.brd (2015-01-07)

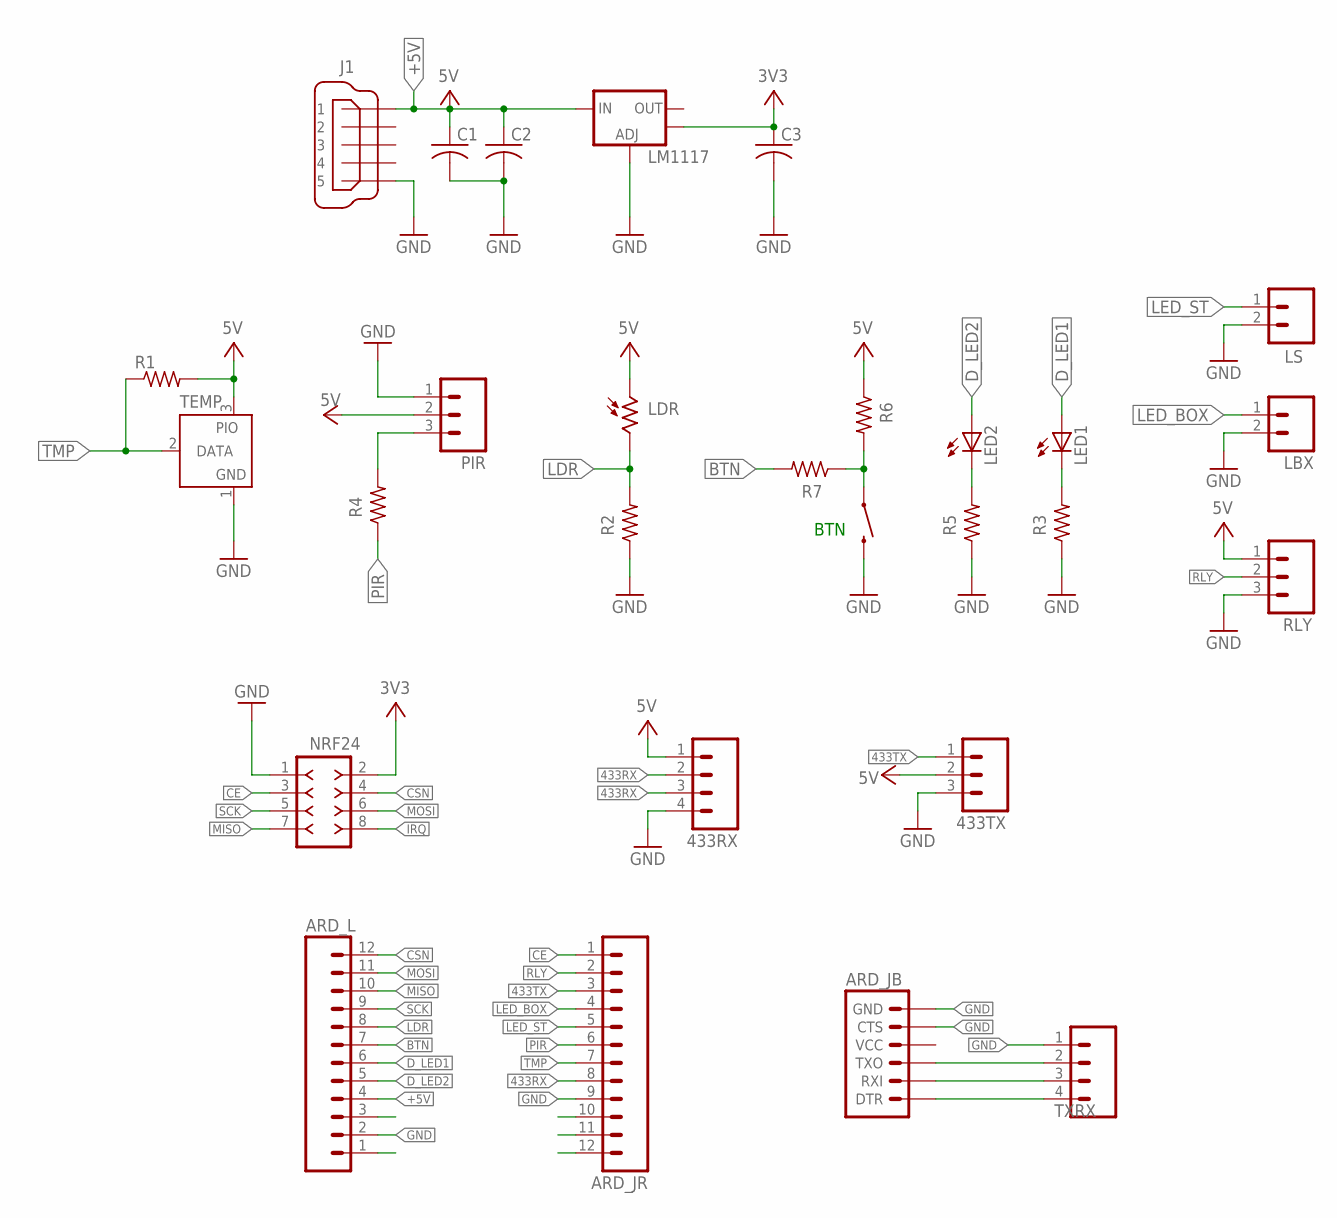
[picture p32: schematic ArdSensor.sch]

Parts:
433RX: M04PTH; 1X04
433TX: M03PTH; 1X03
ARD_JB: ARDUINO_SERIAL_PROGRAMPTH; 1X06
ARD_JR: M12PTH; 1X12
ARD_L: M12PTH; 1X12
BTN: SWITCH-MOMENTARY-2SMD-1101NE; TACTILE-SWITCH-1101NE
C1, C2, C3: C-USC0805; C0805
J1: MICRO-USB-ZX62R-B-5P; ZX62R-B-5P
LBX: M02PTH; 1X02
LDR: D11; BPX65
LED1, LED2: LEDCHIPLED_0805; CHIPLED_0805
LM1117: V_REG_LM1117SOT223; SOT223
LS: M02PTH; 1X02
NRF24: F-2X04-DIL-100; DIL-100-2X04
PIR: M03PTH; 1X03
R1, R2, R3, R4, R5, R6, R7: R-US_R0805; R0805
RLY: M03PTH; 1X03
TEMP: DS2405; TO92-
TXRX: M04PTH; 1X04

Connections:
433RX: 433RX.2, 433RX.3, ARD_JR.8
433TX: 433TX.1, ARD_JR.3
+3V3: C3.1, LM1117.4 (OUT), NRF24.2
+5V: 433RX.1, 433TX.2, ARD_L.4, C1.1, C2.1, J1.1, LDR.A (1), LM1117.3 (IN), PIR.2, R1.2, R6.1, RLY.1, TEMP.3 (PIO)
BTN: ARD_L.7, R7.2
CE: ARD_JR.1, NRF24.3
CSN: ARD_L.12, NRF24.4
D_LED1: ARD_L.6, LED1.A
D_LED2: ARD_L.5, LED2.A
GND: 433RX.4, 433TX.3, ARD_JB.5 (CTS), ARD_JB.6 (GND), ARD_JR.9, ARD_L.2, BTN.2, C1.2, C2.2, C3.2, J1.5, LBX.2, LM1117.1 (ADJ), LS.2, NRF24.1, PIR.1, R2.1, R3.1, R5.1, RLY.3, TEMP.1 (GND), TXRX.1
IRQ: NRF24.8
LDR: ARD_L.8, LDR.K (2), R2.2
LED_BOX: ARD_JR.4, LBX.1
LED_ST: ARD_JR.5, LS.1
MISO: ARD_L.10, NRF24.7
MOSI: ARD_L.11, NRF24.6
unnamed: LED2.C, R5.2
unnamed: LED1.C, R3.2
unnamed: PIR.3, R4.2
unnamed: BTN.1, R6.2, R7.1
unnamed: ARD_JB.3 (TXO), TXRX.2
unnamed: ARD_JB.2 (RXI), TXRX.3
unnamed: ARD_JB.1 (DTR), TXRX.4
PIR: ARD_JR.6, R4.1
RLY: ARD_JR.2, RLY.2
SCK: ARD_L.9, NRF24.5
TMP: ARD_JR.7, R1.1, TEMP.2 (DATA)

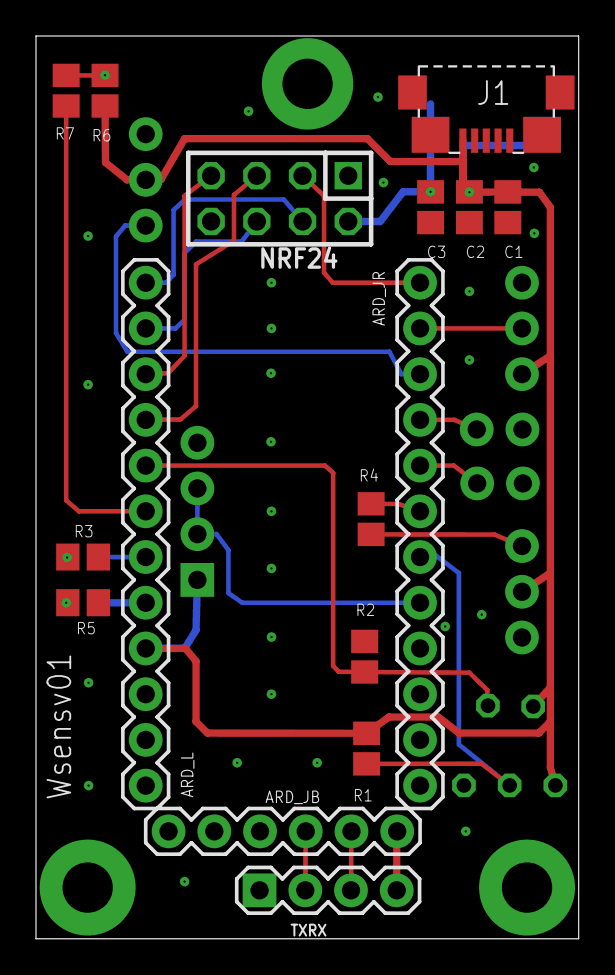
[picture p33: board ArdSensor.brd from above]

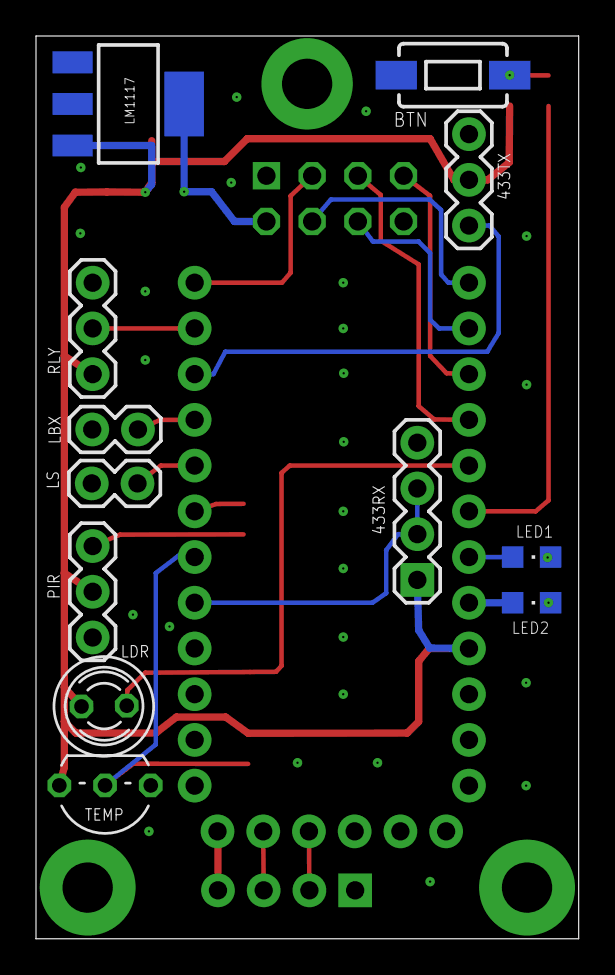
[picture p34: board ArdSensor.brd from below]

Board: 2 copper layers, 30.1 x 50.2 mm, 28 parts (12 on the bottom side), 26 nets.

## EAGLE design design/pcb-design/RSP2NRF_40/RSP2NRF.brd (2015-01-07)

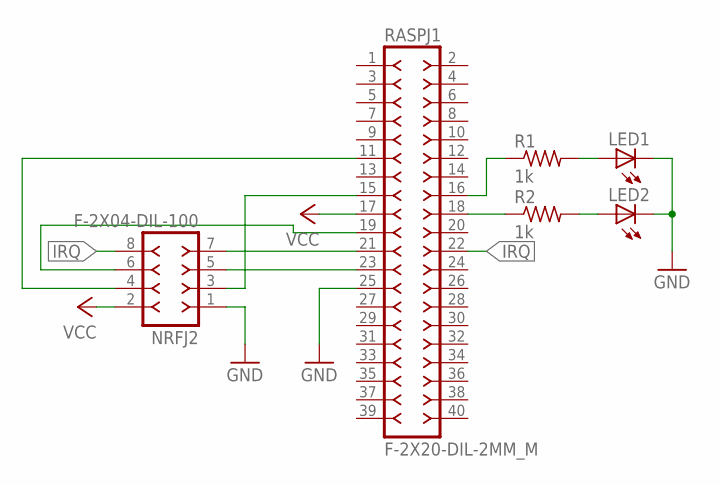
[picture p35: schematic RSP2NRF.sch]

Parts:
LED1, LED2: LEDCHIPLED_0805; CHIPLED_0805; MPN OVS-0808
NRFJ2: F-2X04-DIL-100; DIL-100-2X04
R1, R2: 1k; R0805; MPN CRCW20101K00FKEF
RASPJ1: F-2X20-DIL-2MM_M; DIL-2MM-2X20_M

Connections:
GND: LED1.C, LED2.C, NRFJ2.1, RASPJ1.25
IRQ: NRFJ2.8, RASPJ1.22
unnamed: NRFJ2.5, RASPJ1.23
unnamed: NRFJ2.7, RASPJ1.21
unnamed: NRFJ2.6, RASPJ1.19
unnamed: R2.1, RASPJ1.18
unnamed: NRFJ2.4, RASPJ1.11
unnamed: NRFJ2.3, RASPJ1.15
unnamed: LED2.A, R2.2
unnamed: R1.1, RASPJ1.16
unnamed: LED1.A, R1.2
S$2: RASPJ1.13
VCC: NRFJ2.2, RASPJ1.17


Board: 2 copper layers, 30.8 x 53.3 mm, 6 parts (1 on the bottom side), 12 nets.

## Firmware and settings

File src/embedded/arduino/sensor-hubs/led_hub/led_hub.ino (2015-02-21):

#include <OneWire.h>
#include <DallasTemperature.h>
#include <nRFModule.h>
#include <SPInterface.h>
#include "wise_rfcomm.h"
#include "sensors/sensors.h"
#include "sensors/common.h"
#include "sensors/nrf24l01_receiver_handler.h"
#include "sensors/device_methods.h"

#define DISCOVERY_MODE_INTERVAL		                  120000
#define DISCOVERY_MODE_TIMEOUT                            5000
#define CONNECTED_MODE_READ_SENSORS_INTERVAL              1000
#define CONNECTED_MODE_READ_SENSORS_AS_KEEPALIVE_INTERVAL 20000

#define DIGITAL_RELAY_ADDR_1    1
#define DIGITAL_RELAY_ADDR_2    2
#define DIGITAL_RELAY_ADDR_3    3

#define DIGITAL_RELAY_PIN_1     5
#define DIGITAL_RELAY_PIN_2     6
#define DIGITAL_RELAY_PIN_3     7

uint8_t rx[32];
uint8_t tx[32];

spi_interface 		spi     		  = spi_interface();
NRF24L01    		nrf     		  = NRF24L01(&spi);
WiseRFComm*             net                       = NULL;

rfcomm_data*   		nrfRXPacket 		  = NULL;
rfcomm_data*   		nrfTXPacket 		  = NULL;
rfcomm_device_prot*     prot                      = NULL;
rfcomm_sensor_info*	next_sensor_info_slot 	  = NULL;

#define MAPPING_SIZE    3
sensor_t mapping[] = {
  { DIGITAL_RELAY_ADDR_1,  DIGITAL_RELAY_PIN_1,  RELAY_SENSOR_TYPE, 0 , 5},
  { DIGITAL_RELAY_ADDR_2,  DIGITAL_RELAY_PIN_2,  RELAY_SENSOR_TYPE, 0 , 5},
  { DIGITAL_RELAY_ADDR_3,  DIGITAL_RELAY_PIN_3,  RELAY_SENSOR_TYPE, 0 , 5}
};

device_context_t device_context = { mapping, MAPPING_SIZE, DISCOVERY, 0, 0, NO, 0,
                                    {0xFA, 0xFA, 0xFA, 0xFA, 0xFA}, 
                                    {0x05, 0x04, 0x03, 0x02, 0x02},
                                    {0xFA, 0xFA, 0xFA, 0xFA, 0xFA},
                                    millis(), millis(), millis(), millis() };

void
network_layer_broadcast_arrived_handler () {
  Serial.println ("(LED_CUBE)# Broadcast data [NULL]");
}

void
network_layer_data_arrived_handler () {
  nrf24l01_receiver_handler (nrfRXPacket, &device_context);
}

void
hardware_layer_data_arrived_handler () {
  net->parseRXRawData ();
}

void setup () {
  Serial.begin(57600);
  nrf.init (10, 9); // default csn = 7, ce = 8 (10, 9 on imall board)
  net = new WiseRFComm(&nrf, tx, rx, hardware_layer_data_arrived_handler);
  net->setSender (device_context.local_address);
  net->setDataHandler (network_layer_data_arrived_handler);
  net->setBroadcastHandler (network_layer_broadcast_arrived_handler);
  
  nrfRXPacket = (rfcomm_data *)net->rx_ptr;
  nrfTXPacket = (rfcomm_data *)net->tx_ptr;
  
  pinMode (device_context.mapping_ptr[DIGITAL_RELAY_ADDR_1 - 1].pin, OUTPUT);
  pinMode (device_context.mapping_ptr[DIGITAL_RELAY_ADDR_2 - 1].pin, OUTPUT);
  pinMode (device_context.mapping_ptr[DIGITAL_RELAY_ADDR_3 - 1].pin, OUTPUT);

  Serial.println("(LED_CUBE)# Initialized...");
}

void loop () {
  net->listenForIncoming ();
  
  // Change to DISCOVERY mode
  if (abs (millis () - device_context.discovery_interval) > DISCOVERY_MODE_INTERVAL) {
    Serial.println ("(LED_CUBE)# Change MODE (DISCOVERY)");
    device_context.state = DISCOVERY;
    device_context.discovery_interval = millis ();
  }
  
  // STATE MACHINE
  switch (device_context.state) {
    case DISCOVERY:
      if (abs (millis () - device_context.discovery_timeout) > DISCOVERY_MODE_TIMEOUT) {
        Serial.println ("(LED_CUBE)# DISCOVERY");
        device_context.state = DISCOVERY;
        memcpy (device_context.server_address, device_context.broadcast_address, 5);
        // Send DISCOVERY packet
        send_discovery (&device_context, net);
        device_context.discovery_timeout = millis ();
      }
    break;
    case CONNECTED:
      // Read sensors data each second
      if (abs (millis () - device_context.connected_read_sensors_interval) > CONNECTED_MODE_READ_SENSORS_INTERVAL) {
        Serial.println ("(LED_CUBE)# CONNECTED");
        device_context.mapping_ptr[DIGITAL_RELAY_ADDR_1 - 1].value = 
                  (uint16_t) read_digital_relay_info (device_context.mapping_ptr[DIGITAL_RELAY_ADDR_1 - 1].pin);
          
        device_context.mapping_ptr[DIGITAL_RELAY_ADDR_2 - 1].value = 
                  (uint16_t) read_digital_relay_info (device_context.mapping_ptr[DIGITAL_RELAY_ADDR_2 - 1].pin);
        
        device_context.mapping_ptr[DIGITAL_RELAY_ADDR_3 - 1].value = 
                  (uint16_t) read_digital_relay_info (device_context.mapping_ptr[DIGITAL_RELAY_ADDR_3 - 1].pin);

        // Check for changes
        device_context.is_sync = check_sensors_change (&device_context);
        device_context.connected_read_sensors_interval = millis ();
      }
      
      if (abs (millis () - device_context.connected_read_sensors_as_keepalive_interval) > CONNECTED_MODE_READ_SENSORS_AS_KEEPALIVE_INTERVAL) {
        send_sensors_data (&device_context, net);
        device_context.connected_read_sensors_as_keepalive_interval = millis ();
      }
      
      if (device_context.is_sync == YES) {
        // Send packet with sensors data
        send_sensors_data (&device_context, net);
        device_context.is_sync = NO;
        
        Serial.print ("(LED_CUBE)# Sensors : ");
        Serial.print ((uint8_t)device_context.mapping_ptr[DIGITAL_RELAY_ADDR_1 - 1].value);
        Serial.print (" ");
        Serial.print ((uint8_t)device_context.mapping_ptr[DIGITAL_RELAY_ADDR_2 - 1].value);
        Serial.print (" ");
        Serial.println ((uint8_t)device_context.mapping_ptr[DIGITAL_RELAY_ADDR_3 - 1].value);
      }
      
      if (device_context.is_res_ack == YES) {
        device_context.mapping_ptr[device_context.res_ack_port - 1].value =
          (uint16_t) read_digital_relay_info (device_context.mapping_ptr[device_context.res_ack_port - 1].pin);
        delay (100);
        send_sensors_data_with_ack (&device_context, net, device_context.res_ack_port);
        device_context.is_res_ack = NO;
        
        Serial.print ("(LED_CUBE)# Sensors : ");
        Serial.print ((uint8_t)device_context.mapping_ptr[DIGITAL_RELAY_ADDR_1 - 1].value);
        Serial.print (" ");
        Serial.print ((uint8_t)device_context.mapping_ptr[DIGITAL_RELAY_ADDR_2 - 1].value);
        Serial.print (" ");
        Serial.println ((uint8_t)device_context.mapping_ptr[DIGITAL_RELAY_ADDR_3 - 1].value);
      }
    break;
  }
}

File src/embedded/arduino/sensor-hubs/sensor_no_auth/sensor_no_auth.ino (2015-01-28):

#include <OneWire.h>
#include <DallasTemperature.h>
#include <nRFModule.h>
#include <SPInterface.h>
#include "wise_rfcomm.h"
#include "sensors/sensors.h"
#include "sensors/common.h"
#include "sensors/nrf24l01_receiver_handler.h"
#include "sensors/device_methods.h"

#define DISCOVERY_MODE_INTERVAL                             120000
#define DISCOVERY_MODE_TIMEOUT                              5000
#define CONNECTED_MODE_READ_SENSORS_INTERVAL                1000
#define CONNECTED_MODE_READ_SENSORS_AS_KEEPALIVE_INTERVAL   30000

#define ANALOG_LDR_ADDR             1

#define DIGITAL_TEMPERATURE_PIN     2
#define ANALOG_LDR_PIN              2
#define DIGITAL_PIR_PIN             4
#define DIGITAL_RELAY_PIN           5

uint8_t rx[32];
uint8_t tx[32];

spi_interface 		    spi     		  = spi_interface();
NRF24L01    		    nrf     		  = NRF24L01(&spi);
WiseRFComm*             net               = NULL;

rfcomm_data*   		nrfRXPacket 		  = NULL;
rfcomm_data*   		nrfTXPacket 		  = NULL;
rfcomm_device_prot*     prot              = NULL;
rfcomm_sensor_info*	next_sensor_info_slot = NULL;

#define MAPPING_SIZE    1
sensor_t mapping[] = {
  { ANALOG_LDR_ADDR, ANALOG_LDR_PIN, LUMINANCE_SENSOR_TYPE, 0 , 30 }
};

device_context_t device_context = { mapping, MAPPING_SIZE, DISCOVERY, 0, 0,
                                    {0xFA, 0xFA, 0xFA, 0xFA, 0xFA}, 
                                    {0x06, 0x04, 0x03, 0x02, 0x01},
                                    {0xFA, 0xFA, 0xFA, 0xFA, 0xFA},
                                    millis(), millis(), millis(), millis() };

void setup () {
    Serial.begin(9600);
    nrf.init (10, 9); // default csn = 7, ce = 8 (10, 9 on imall board)
    net = new WiseRFComm(&nrf, tx, rx, NULL);
    net->setSender (device_context.local_address);

    nrfRXPacket = (rfcomm_data *)net->rx_ptr;
    nrfTXPacket = (rfcomm_data *)net->tx_ptr;

    Serial.println("(TLM)# Initialized...");
}

void loop () {
    // Read sensors data each second
    if (abs (millis () - device_context.connected_read_sensors_interval) > CONNECTED_MODE_READ_SENSORS_INTERVAL) {
        device_context.mapping_ptr[ANALOG_LDR_ADDR - 1].value = 
            data_noise_reduse( device_context.mapping_ptr[ANALOG_LDR_ADDR - 1].value,
                (uint16_t) read_analog_luminance_info (device_context.mapping_ptr[ANALOG_LDR_ADDR - 1].pin), 2);

        // Check for changes
        device_context.is_sync = check_sensors_change (&device_context);
        device_context.connected_read_sensors_interval = millis ();
    }

    if (abs (millis () - device_context.connected_read_sensors_as_keepalive_interval) > CONNECTED_MODE_READ_SENSORS_AS_KEEPALIVE_INTERVAL) {
        send_sensors_data_no_auth (&device_context, net);
        device_context.connected_read_sensors_as_keepalive_interval = millis ();
    }

    if (device_context.is_sync == YES) {
        // Send packet with sensors data
        send_sensors_data_no_auth (&device_context, net);
        device_context.is_sync = NO;

        Serial.print ("(TLM)# Sensors : ");
        Serial.print ((uint8_t)device_context.mapping_ptr[ANALOG_LDR_ADDR - 1].value);
        Serial.println ();
    }
}

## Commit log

2014-10-21 first commit - working environment
    [BOX_UP 1.1.STL, BOX_UP Support 1.1.STL, Cover 3.1.STL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]
2014-10-24 linux: added ack management for resending requests to client
    added couple defines
2014-10-25 linux: added sensors availability
2014-10-25 php: added sensors availability
2014-10-25 db: added sensors availability
2014-11-01 embedded: sensors send data only on change added keep alive option
2014-11-01 docs: added new document for pcbs and enclosures future designs
2014-11-08 linux: added chached sensor database to client handler module
    and more ...
2014-11-14 linux: added 433mhz wiseup (built by Omer) sensors support
2014-11-14 embedded: added new sensor hub and sensor
2014-11-26 linux: db updated only on sensor data change
2014-11-26 php: sensor spred all over the dashboard
2014-11-26 linux: timer fix
2014-11-29 linux & php: robustness fix #1
    [wiseDBMng.h]
2014-11-30 embedded: focus on one sensor hub (motion temperature luminance and led) added feature - each sensor send its update interval to the gateway
2014-11-30 repository: drivers for unknown usb to uart chip on chip nano arduino board
2014-12-01 linux & php: added connection from php to the deamon based on unix domain sockets
2014-12-02 linux: start of app framework
2014-12-06 Design: Added Enclosure Design for Raspberry Pi B+
    [Case Rasp Bplus - Bottom.SLDPRT, Case Rasp Bplus - Bottom.STL, Case Rasp Bplus - Top.SLDPRT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]
2014-12-27 Added thread safe access to nrf24l01
    Added sleep for 10 micro sec to spi_write method (magically it fixed a major bug)
    Added hiredis libaray
    removed lot of code
    [wiseDBMng.h]
2014-12-27 Added node.js example communication with Sensors FW via redis PUBSUB
2015-01-06 PCB design : initial checkin
    [433TMP.brd, 433TMP.sch, ArdSensor.brd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]
2015-01-06 first working draft - connected to redis and mongodb with an API that exposes SSE and /api/sensors
2015-01-06 docs: initial NRF on battery document
2015-01-07 created table to see sensor values
2015-01-13 docs: removed all doc files and copied to dropbox
    [WiseUp.xlsx]
2015-01-15 pcb design: sensor hub update
    [AtmelSMD328NRF.brd, AtmelSMD328NRF.sch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]
2015-01-26 node.js: fix for initial sensor info database write
2015-01-26 node.js: test framework adopt the changes
2015-01-28 linux: added anonimus sensor info SENSOR_INFO_DATA_NO_AUTH_TYPE
2015-01-28 embedded: added anonymous sensor example
2015-02-01 general layout + menu navigation + sensors ui
2015-02-01 formatted the document and added some comments + fix for sensor action bug
2015-02-04 pcb-design: added new schematics for 5v switch/sensor base
    [5v-switch-sensor.sch]
2015-02-06 pcb-design: new board file for 5v-switch-sensor and fixes for sch file.
    [5v-switch-sensor.brd, 5v-switch-sensor.sch]
2015-02-06 pcb-design: [5v-switch-sensor] added noise reduction to IR circuit
    [5v-switch-sensor.brd, 5v-switch-sensor.sch]
2015-02-07 pcb-design: 5v pcb fixes before sendinf to imall and start of 3v pcb
    [3v-battery-sensor.sch, 5v-switch-sensor.brd, 5v-switch-sensor.sch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]
2015-02-14 cordova-app: added new switch module (initial work)
2015-02-14 embedded: added new luminance (ldr) sensor and changed little bit led_hub
2015-02-16 cordova-app: added html removal by sensor type
2015-02-19 refactored sensors directive

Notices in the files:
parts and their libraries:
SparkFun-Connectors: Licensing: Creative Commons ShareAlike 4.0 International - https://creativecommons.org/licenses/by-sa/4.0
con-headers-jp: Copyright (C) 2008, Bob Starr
